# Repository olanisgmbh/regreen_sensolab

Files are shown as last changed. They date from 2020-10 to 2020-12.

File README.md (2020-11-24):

# SensoLAB - make, learn and share

The vision of this project is to implement an universal platform which can be used as a citizen science tool and an interdisciplinary tool for schools.

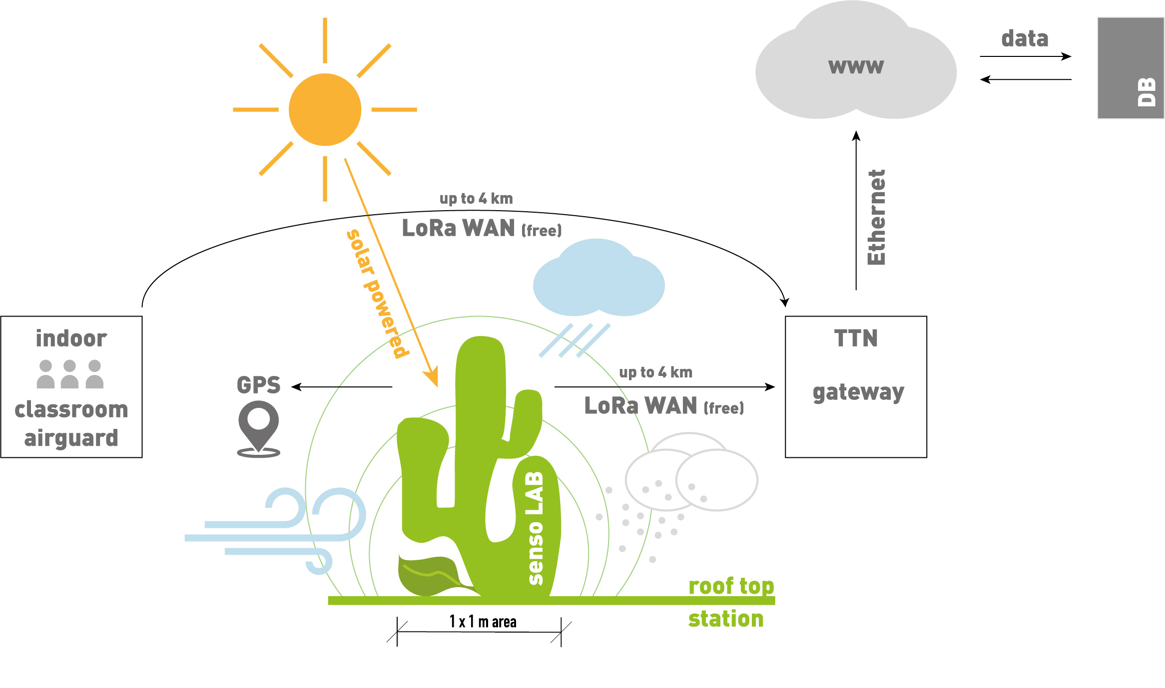
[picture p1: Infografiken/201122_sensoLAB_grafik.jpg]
first prototype


#### the tools You need:

+ screwdrivers
+ solderstation
+ circle cutter
+ punching iron ( 3mm, 8mm )
+ a dremel milling/drilling tool
+ hammer

# Author
Norman Rembarz <norman.rembarz@olanis.de>

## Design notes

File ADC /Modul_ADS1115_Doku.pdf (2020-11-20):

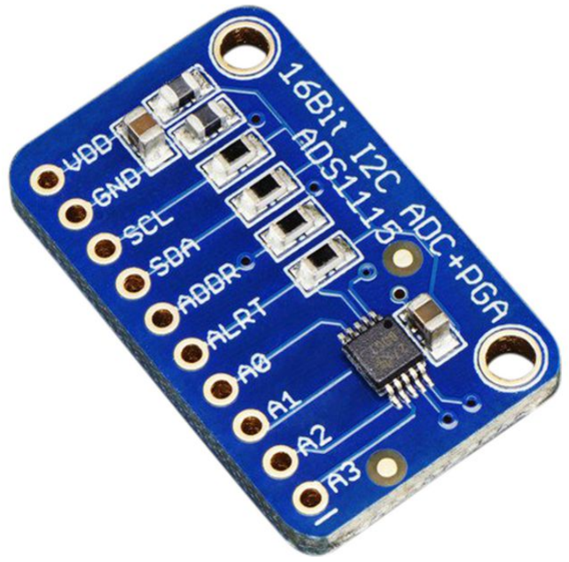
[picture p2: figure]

Von der Spannung zum Bit mit dem ADS1115

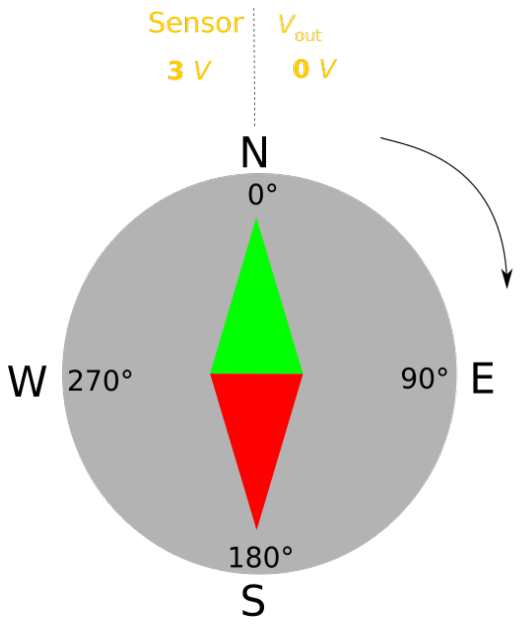
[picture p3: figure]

Was ist ein ADC?
ADC steht für AnalogDigitalConverter, auch A/D-Wandler oder Umsetzer genannt. Dieser ermöglicht es analoge Signale zu digitalen Signalen umzuwandeln. A/D-Umsetzer sind im Bereich der Elektronik unverzichtbar und so gut wie in jedem Elektrogerät vorhanden, so auch in Arduinos. Das Gegenstück hierzu wird DAU genannt. Es gibt viele Arten analoge Signale in digitale umzuwandeln, je nach tiefe handelt es sich dabei um sehr komplexe Prozesse und so sind diese Verfahren bis zum heutigen Tag noch immer Thema aktueller Forschungen im Bereich Elektrotechnik und Informatik.

Auflösung und Sample Rate
Für den Hobbybereich gibt es zwei relevante Werte um mit den Modulen arbeiten zu können, die Auflösung und die Abtastrate. Die Abtastrate bestimmt, wieviele Veränderungen des Signals erfasst werden können. Im Prinzip also der horizontale Abstand der gepunkteten Linien unten im Bild:
Regreen SensorLAB Dokumentation – Wandlung von analog zu digital | Seite 1

Drawing 1: angles and voltage

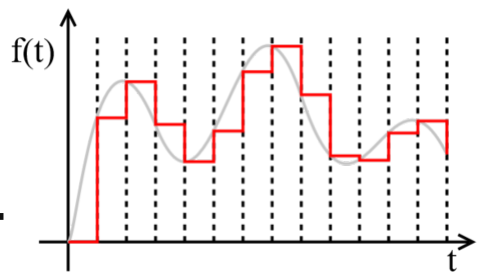
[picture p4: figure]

Die Auflösung kann als Anzahl möglicher Stufen verstanden werden und ist in der nächsten Abbildung als vertikaler Abstand der horizontalen Linien zu verstehen (x).

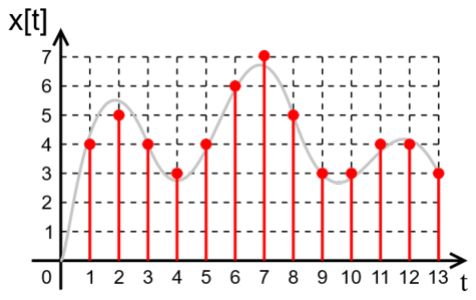
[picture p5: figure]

Was ist ein PGA?
PGA steht für Programmable Gain Amplifier was übersetzt soviel wie "programmierbarer Verstärker" heißt. Diese dienen primär als Operationsverstärker in der Messtechnik, wir verwenden diese Funktion des ADUs auf unseren Modulen nur recht selten, da unsere analogen Sensoren "outof-the-box" für unsere Mikrocontroller lesbare Werte liefern.
Wieso I2C?
Über das I2C-Interface ist eine Kommunikation zwischen dem Modul (auch mehreren Modulen) und Mikrocontrollern mit nur zwei Datenleitungen möglich. Der Umgang mit dem I2C-Bus ist vor allem für Einsteiger empfehlenswert wenn auch nicht mehr Stand der Technik. Alle gängigen Mikrocontroller können über dieses Protokoll kommunizieren und der Umgang der Sensoren auf Modul-Ebene (mit Library) ist besonders leicht zu erlernen. Für fortgeschrittene Benutzer sei an der Stelle die alternativen I2S und CAN genannt.
Regreen SensorLAB Dokumentation – Wandlung von analog zu digital | Seite 2

Installation des Sensors

Damit der Windrichtungsmesser seine Funktion erfüllen kann, muss bei der Installation darauf geachtet werden, dass die NORD-Markierung am Gehäusefuß des Gerätes in die tatsächliche Nord-Richtung zeigt. Hierzu eignet sich die Kompassfunktion im Smartphone oder einer App – wer einen traditionellen mechanischen Kompass zur Hand hat, kann natürlich auch diesen nehmen. Einfach beide N-S-Positionen deckungsgleich aufeinander bringen. Dies ist hinreichend genau für unsere Messungen. Weiterhin ist darauf zu achten, dass die Drehachse des Sensors lotrecht steht.

Funktionsweise

Die Windfahne des Messgeräts ist sehr leichtgängig gelagert und richtet sich zuverlässig nach der vorherrschenden Luftströmung aus. Die Elektronik im Sensor wertet dabei die Stellung der Windfahne aus und wandelt diese in einen Spannungswert zwischen 0 und 3 Volt um (siehe Abbildung 1). Diese Spannung liegt am Signalausgang des Gerätes an. Eine Auslenkung von 90° vom geografischen Nordpol (im UZS) entspricht dabei der Himmelsrichtung OST. Der Spannungswert am Ausgang steigt dabei auf ein Viertel des Wertebereichs an. Am Beispiel OST auf etwa 750 Millivolt.

Um diese Spannung an unserem Mikrocontroller messen zu können, benötigen wir einen Analog zu Digital Konverter, da unser Mikrocontroller keine analogen Eingänge besitzt.
Hier verwenden wir einen ADS1115. Dies ist ein Wandler, der vier analoge Eingänge bereitstellt, welche mit einer 16bit Genauigkeit in digitale Werte umgewandelt werden können und anschließend über die I²C Schnittstelle ausgelesen werden.

Anschluss der Leitungen

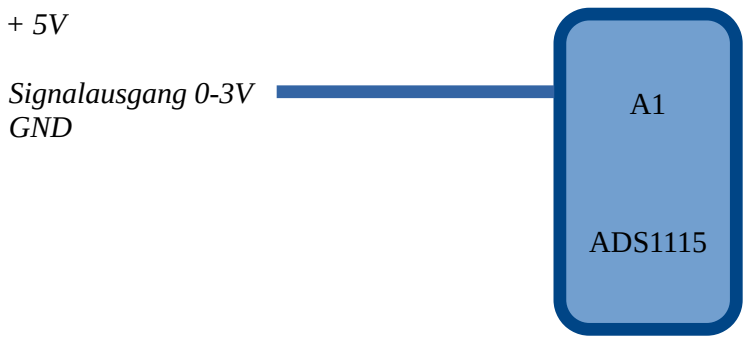
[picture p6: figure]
Signalausgang 0-3V GND; ADS1115

GND

Quellen und Links

- Wikipedia Windrichtungsmessung
- Link zum China-Importeur
Regreen SensorLAB Dokumentation – Wandlung von analog zu digital | Seite 3

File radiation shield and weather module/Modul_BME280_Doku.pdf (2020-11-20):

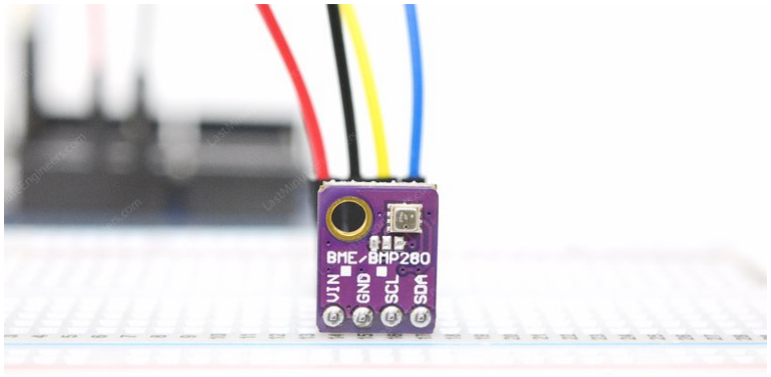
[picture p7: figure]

Temperatur, Luftdruck und Luftfeuchte – der BME280

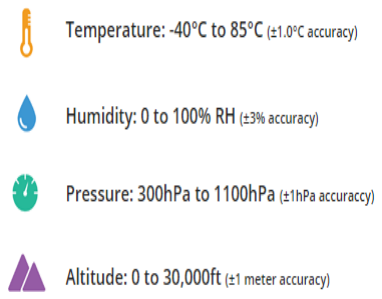
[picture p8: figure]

Bosch Sensortec bringt eine Weltneuheit im Bereich der Sensoren-Technologie auf den Markt: Die integrierte Sensoreinheit BME280 vereint die Sensorfunktionen für Luftdruck, Luftfeuchtigkeit und Temperatur in einem einzigen Gehäuse. Der neue Sensor von Bosch Sensortec wurde speziell entwickelt, um eine Vielzahl neuer und leistungsfähiger Anwendungen zu unterstützen, wie etwa Indoor-Navigation, Smart Home, personalisierte Wetterstationen oder Sport- und Fitness-Applikationen. Die präzise Messfunktion des BME280 ist eine entscheidende Voraussetzung beispielsweise für die Indoor-Navigation mit stockwerksgenauer Höhenermittlung, da diese eine sehr hohe Genauigkeit, einen geringen Temperaturdrift und eine hohe Auflösung erfordert. Der BME280 bestimmt die Luftfeuchtigkeit in nur einer Sekunde – die branchenweit kürzeste Reaktionszeit. Zudem zeichnet er sich durch eine sehr hohe Präzision bei der Messung der Umgebungstemperatur und einen niedrigen Energiebedarf aus.

Auslesen der Daten

Serial.print("Temperature = "); Serial.print(bme.readTemperature()); Serial.println("*C");

Serial.print("Pressure = "); Serial.print(bme.readPressure() / 100.0F); Serial.println("hPa");

Serial.print("Approx. Altitude = "); Serial.print(bme.readAltitude(SEALEVELPRESSURE_HPA));
Serial.println("m");
Regreen SensorLAB Dokumentation – Wandlung von analog zu digital | Seite 1

Drawing 1: Wertebereich des BME280

Serial.print("Humidity = "); Serial.print(bme.readHumidity()); Serial.println("%");

I²C Adresse
0x76 (ist die Standardadresse)
0x77 (selektiv über spezielle Beschaltung)

Anschluss der Leitungen

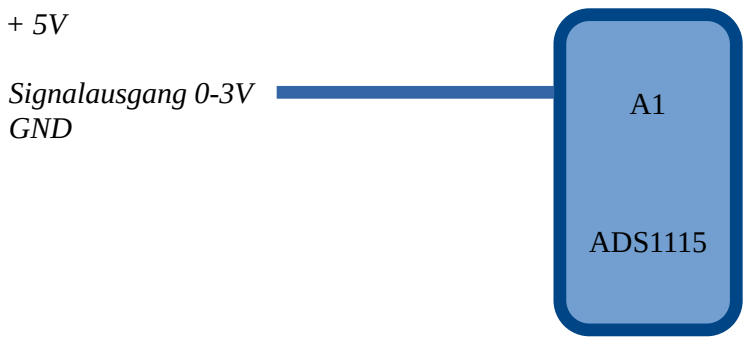
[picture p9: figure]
Signalausgang 0-3V GND; ADS1115

GND

Quellen und Links

- Wikipedia Windrichtungsmessung
- Link zum China-Importeur
Regreen SensorLAB Dokumentation – Wandlung von analog zu digital | Seite 2

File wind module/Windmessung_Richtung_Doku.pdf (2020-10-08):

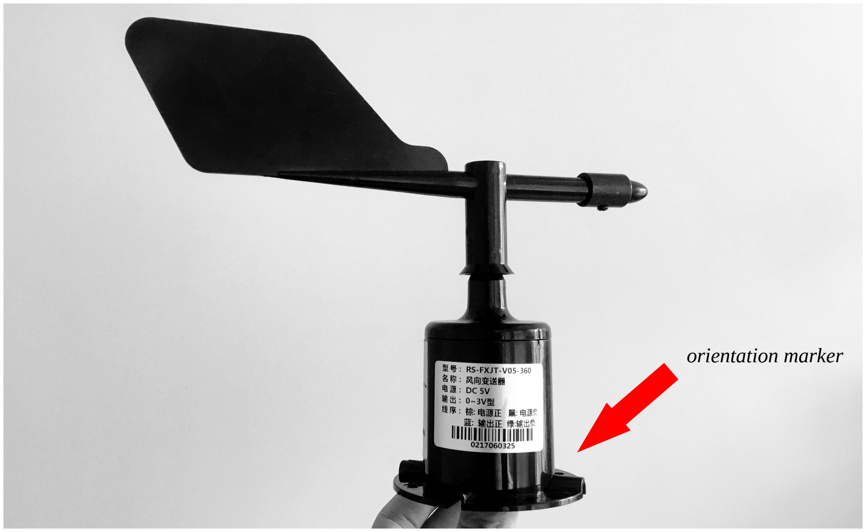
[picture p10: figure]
orientation marker

Windrichtungsmesser mit analogem Signal-Ausgang am ADS1115 (analog zu digital Konverter)


Installation des Sensors

Damit der Windrichtungsmesser seine Funktion erfüllen kann, muss bei der Installation darauf geachtet werden, dass die NORD-Markierung am Gehäusefuß des Gerätes in die tatsächliche Nord-Richtung zeigt. Hierzu eignet sich die Kompassfunktion im Smartphone oder einer App – wer einen traditionellen mechanischen Kompass zur Hand hat, kann natürlich auch diesen
nehmen. | Einfach | beide | N-S-Positionen | deckungsgleich
aufeinander bringen. Dies ist hinreichend genau für unsere Messungen. Weiterhin ist darauf zu achten, dass die Drehachse des Sensors lotrecht steht.

Funktionsweise

Die Windfahne des Messgeräts ist sehr leichtgängig gelagert und richtet sich zuverlässig nach der vorherrschenden Luftströmung aus. Die Elektronik im Sensor wertet dabei die Stellung der Windfahne aus und wandelt diese in einen Spannungswert zwischen 0 und 3 Volt um (siehe Abbildung 1). Diese Spannung liegt am Signalausgang des Gerätes an. Eine Auslenkung von 90° vom geografischen Nordpol (im UZS) entspricht dabei der Himmelsrichtung OST. Der Spannungswert am Ausgang steigt dabei auf ein Viertel des Wertebereichs an. Am Beispiel OST auf etwa 750 Millivolt.

Regreen SensorLAB Dokumentation – Messung der Windrichtung | Seite 1

Drawing 1: angles and voltage

Um diese Spannung an unserem Mikrocontroller messen zu können, benötigen wir einen Analog zu Digital Konverter, da unser Mikrocontroller keine analogen Eingänge besitzt.
Hier verwenden wir einen ADS1115. Dies ist ein Wandler, der vier analoge Eingänge bereitstellt, welche mit einer 16bit Genauigkeit in digitale Werte umgewandelt werden können und anschließend über die I²C Schnittstelle ausgelesen werden.

Anschluss der Leitungen

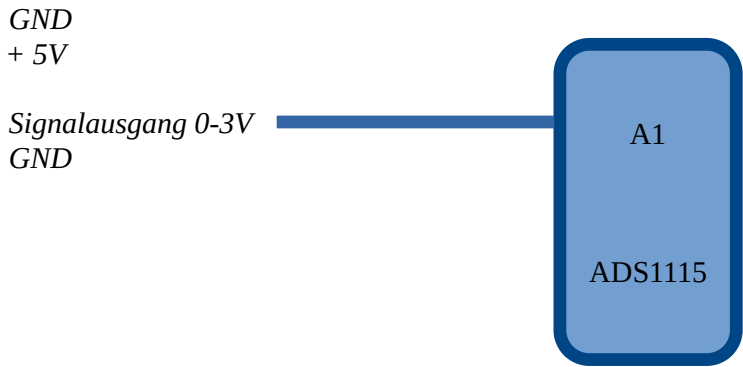
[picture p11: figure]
GND + 5V; Signalausgang 0-3V GND; ADS1115

Regreen SensorLAB Dokumentation – Messung der Windrichtung | Seite 2

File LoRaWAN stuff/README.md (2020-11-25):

# How to install your LoRa Gateway

### Why this technology?

# Where is the best place?

# Author
Norman Rembarz <norman.rembarz@olanis.de>
Philpp Zimmer <philipp.zimmer@olanis.de>

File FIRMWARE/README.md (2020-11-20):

# How to flash the firmware on T-beam

The vision of this project is to implement an universal platform which can be used as a citizen science tool and an interdisciplinary tool for schools.

# All your base belong to us

# Author
Norman Rembarz <norman.rembarz@olanis.de>
Philpp Zimmer <philipp.zimmer@olanis.de>

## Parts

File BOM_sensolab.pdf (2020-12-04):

## complete bill of material - sensoLAB

no. | image | amount | name | specification | avg.price (€) | source | link
1 | | 1 | Flachdachständer / pole stand | 1x1m , 1m length of pole | 40,00 EUR | ebay | click (https://www.ebay.de/itm/Flachdachstander-1m-Mast-4x50x50cm-SAT-Antenne-Standfus-Terrasse-Balkon-Stander/160658726749)
2 | | 4 | Betonplatte / concrete plate | 50x50cm, 4cm thickness | 3,00 EUR | local hardware store | click (https://www.bauhaus.info/terrassenplatten-gehwegplatten/ehl-waschbetonplatte/p/22264864)
3 | | 8 | DN110 angle 45° | DN110 HT | 2,00 EUR | local hardware store | click (https://www.hornbach.de/shop/HT-Bogen-DN-110-45-Grad/266988/artikel.html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)
4 | | 1 | DN110 Muffe | DN110 HT | 2,00 EUR | local hardware store | click (https://www.hornbach.de/shop/HT-Muffe-DN-110-grau/267163/artikel.html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)

5 | 5 | DN110 Deckel / cap | DN110 HT | 1,00 EUR | local hardware store | click (https://www.hornbach.de/shop/HT-Muffenstopfen-DN-110/267185/artikel.html)
6 | 3 | DN110 Rohr / tube | DN110 HT 500mm | 2,00 EUR | local hardware store | click (https://www.obi.de/ht-abflussrohre/marley-ht-rohr-mit-steckmuffe-dn-110-grau-500-mm/p/7436843)
7 | 3 | DN110 Rohr / tube | DN110 HT 250mm | 2,00 EUR | local hardware store | click (https://www.obi.de/ht-abflussrohre/marley-ht-rohr-mit-steckmuffe-dn-110-grau-250-mm/p/7436793)
8 | 1 | DN110 Reinigungsrohr / cleaning tube | DN110 HT | 8,00 EUR | local hardware store | click (https://www.obi.de/ht-reinigungsrohre/marley-ht-reinigungsrohr-dn-110/p/7434772)

9 | 6 | threaded rod | M8 1000mm, stainless steel | 5,00 EUR | local hardware store | click (https://www.edelstahl-niro.de/gewindestange-1000mm-p-1623.html)
10 | 8 | Rohrschelle klein | | 1,50 EUR | local hardware store
11 | 8 | Rohrschelle groß | | 2,00 EUR | local hardware store
100 | 1 | solar panel | 12V, 50W with cables
50,00 EUR | ebay/amazon

110 | 1 | solar panel regulator | 12V MPPT | 20,00 EUR | ebay/amazon | click (https://www.ebay.de/itm/30A-Solar-Laderegler-Controller-MPPT-Solar-Panel-USB-Regulator-12V-24V-DHL/233790688162)
120 | 1 | 12V battery | 12V / 12Ah | 30,00 EUR | ebay/amazon | click (https://www.ebay.de/itm/Kung-Long-VdS-WP12-12-12V-12Ah-AGM-Blei-Accu-Batterie-wartungsfrei-VdS-battery/202978835868)
130 | 1 | cable red | 6qmm, red, 1m | 4,00 EUR | ebay/amazon
140 | 1 | cable black | 6qmm, black 1m | 4,00 EUR | ebay/amazon

150 | 1 | solar cable connector | female | 2,00 EUR | ebay/amazon | click (https://www.ebay.de/itm/Solarstecker-Solar-Stecker-Buchse-Kupplung-Kabel-2-5-6-mm-DE-STOCK/402563089656)
160 | 1 | solar cable connector | male | 2,00 EUR | ebay/amazon | click (https://www.ebay.de/itm/Solarstecker-Solar-Stecker-Buchse-Kupplung-Kabel-2-5-6-mm-DE-STOCK/402563089656)
170 | 1 | pole mounting box | | 25,00 EUR | WLAN-shop24 | click (https://www.wlan-shop24.de/kunststoff-gehaeuse-mastmontage-wetterfest)

200 | 10 | plastic flowerpot coaster | perimeter=130mm, heigth=10mm, white | 15,00 EUR | ebay/amazon | click (https://www.ebay.de/itm/Untersetzer-fur-Blumenkubel-Blumentopf-Blumenuntersetzer-Rund-9-Grosen-4-Farben/141374601466)
210 | 1 | threaded rod | M3x1000mm , stainless steel | 4,00 EUR | local hardware store | click (https://www.ebay.de/itm/Gewindestangen-M3-bis-M20-DIN-975-976-A2-Edelstahl-1-bis-5-Stuck/172937101238)
220 | 6 | M3 nut | stainless steel | 1,00 EUR | local hardware store
230 | 35 | washer 3,2x10 | Stainless steel | 1,00 EUR | Local hardware
240 | 1 | acrylic tube | 3mm/5mm, 1000mm, transparent | 4,00 EUR | ebay/amazon | click (https://www.ebay.de/itm/3-75-m-Acrylrohr-XT-ausen-5-mm-innen-3-mm-transparent-Lange-1-m/322116941955)

250 | 5 | Kabelverschraubung | PG7 10mm | 5,00 EUR | reichelt.de | click (https://www.reichelt.de/kabelverschraubung-pg7-grau-ral-7035-10er-pack-rnd-465-00384-p221969.html?PROVID=2788)
260 | 2 | rubber mat for sealings | 200x300mm, 1mm thick, black | 4,00 EUR | ebay/amazon | click (https://www.ebay.de/itm/Antivibrations-Gummimatte-Gummiplatte-SBR-von-1-bis-4mm-Grose-von-100-bis-500mm/323850603389)
270 | 1 | acrylic dome | 100mm | 14,00 EUR | ebay (www.acrylhaus .com) | click (https://www.ebay.de/itm/Halbkugel-Halbschale-aus-Acrylglas-Plexiglas-100mm/162235277237)
280 | 1 | acrylic ronde | 130mm/4mm | 5,00 EUR | ebay | click (https://www.ebay.de/itm/PLEXIGLAS-RUND-50-1000-mm-4-mm-DICK-ACRYLGLAS-MARKE-DECKEL-GLASKLAR-RONDE/264446582865)
290 | 1 | housing ventilation plug | M12 | 5,00 EUR | www.tme.eu | click (https://www.tme.eu/de/details/gvppa-m12l/gehause-sonstiges-zubehor/fibox/gvppa-m12l/?brutto=1)

300 | 1 | BME280 breakout | PCB with mounting holes, GY-BME280 (3.3V) | 5 | ebay/amazon | click (https://www.tme.eu/de/details/gvppa-m12l/gehause-sonstiges-zubehor/fibox/gvppa-m12l/?brutto=1)
310 | 1 | SPS30 sensor | Sensirion | 38,00 EUR | sos-electronic / olanis | click (https://www.soselectronic.de/products/sensirion/sps30-2-304234)
320 | 1 | SCD30 | Sensirion | 45,00 EUR | sos-electronic / olanis | click (https://www.soselectronic.de/products/sensirion/scd30-5-290529)
330 | 1 | VEML7700 | | 10,00 EUR | olanis

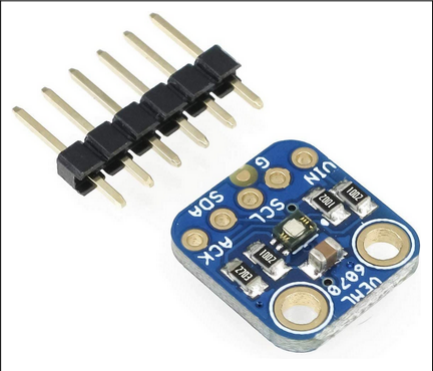
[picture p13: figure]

340 | 1 | VEML6070 | | 10,00 EUR | olanis
350 | 1 | ADS1115 | | 7,00 EUR | olanis
360 | 1 | anemometer | Output 0-3V | 70,00 EUR | ebay/alibaba

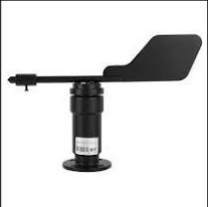
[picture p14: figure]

370 | 1 | wind direction | Output 0-3V | 60,00 EUR | ebay/alibaba
380 | 1 | rain gauge | | 30,00 EUR | ebay/alibaba
390 | 1 | Niederschlagsensor | | 10,00 EUR | ebay
400 | 1 | I²S microphone | | 10,00 EUR | ebay

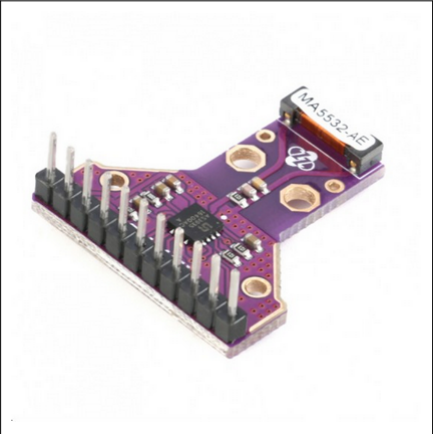
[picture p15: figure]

410 | 1 | AS3935 | I²C connection | 20,00 EUR | ebay

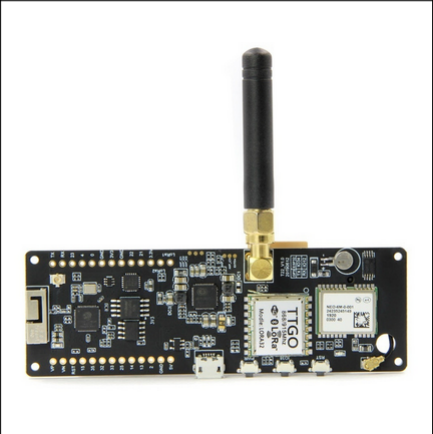
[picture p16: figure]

420 | 1 | TTGO T-Beam | V1.1, 868MHz (EU) | 30,00 EUR | ebay

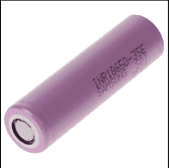
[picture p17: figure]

430 | 1 | Battery 18650 | 3.7V | 6,00 EUR | ebay
440 | 1 | antenna pigtail | SMA | 3,00 EUR | ebay

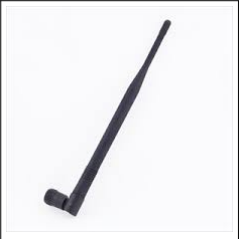
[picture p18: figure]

450 | 1 | antenna | For 868MhZ, SMA connector | 9,00 EUR | ebay

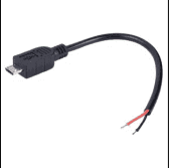
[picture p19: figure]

460 | 1 | MicroUSB cable | Power cable, 15cm DeLock | 3,00 EUR | ebay
total | 624,50 EUR
500 | 1 | LoRaWAN Gateway | Kit with antenna, gateway and power supply
280,00 EUR | ebay

total with
gateway

904,50 EUR

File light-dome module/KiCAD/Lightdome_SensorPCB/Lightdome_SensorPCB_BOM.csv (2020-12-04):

Reference | Value | Footprint | Datasheet | MANUFACTURER | PARTREV | STANDARD
U1 | VEML6070 | VEML6070:PHODET_VEML6070 |  | Vishay
U2 | VEML7700-TT | VEML7700-TT:XDCR_VEML7700-TT |  | Vishay | 1.3 | Manufacturer Recommendation
U3 | P82B715D | SOIC127P599X175-8N
R1 | 330 | Resistor_SMD:R_1206_3216Metric_Pad1.42x1.75mm_HandSolder | ~
J1 | Conn_01x04 | Connector_JST:JST_PH_B4B-PH-SM4-TB_1x04-1MP_P2.00mm_Vertical | ~
R2 | 330 | Resistor_SMD:R_1206_3216Metric_Pad1.42x1.75mm_HandSolder | ~
R3 | 270K | Resistor_SMD:R_0603_1608Metric_Pad1.05x0.95mm_HandSolder | ~
C1 | 100n | Capacitor_SMD:C_0603_1608Metric_Pad1.05x0.95mm_HandSolder | ~

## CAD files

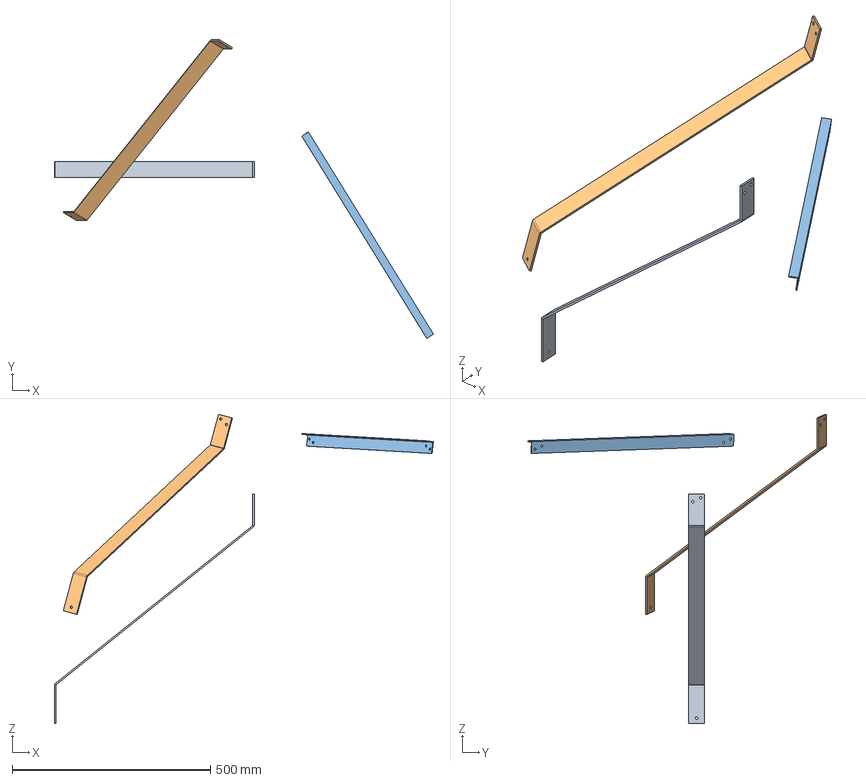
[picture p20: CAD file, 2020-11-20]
solar panel mount/drawings/solar_panel_mount_assembly.FCStd
956.1 x 753.7 x 780.5 mm
solar_panel_mount_bracket_1_003
solar_panel_mount_bracket_1_001
solar_panel_mount_bracket_2_002

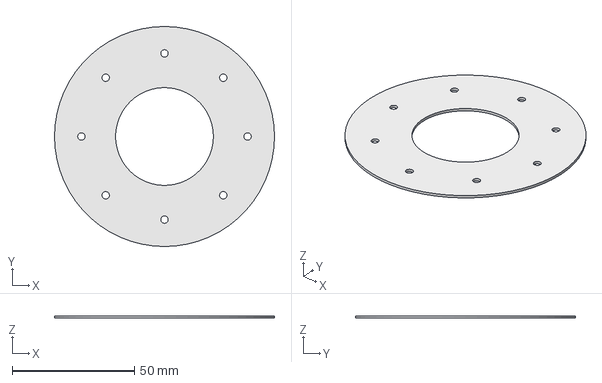
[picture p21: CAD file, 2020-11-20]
light-dome module/drawings/step/rubber_ring_spacer.step
90.0 x 90.0 x 1.00 mm

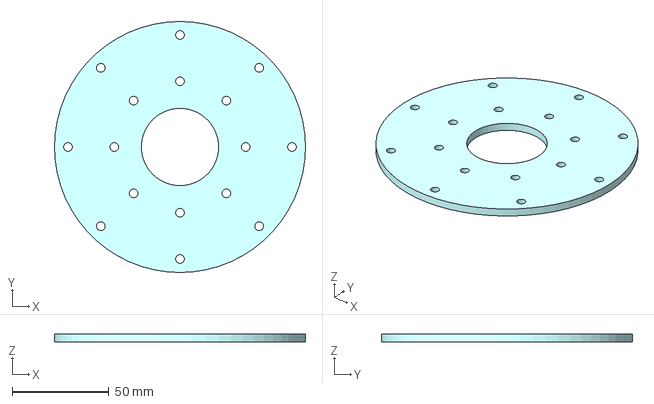
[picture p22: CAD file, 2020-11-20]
light-dome module/drawings/top_plate_LightDome.FCStd
130.0 x 130.0 x 4.00 mm

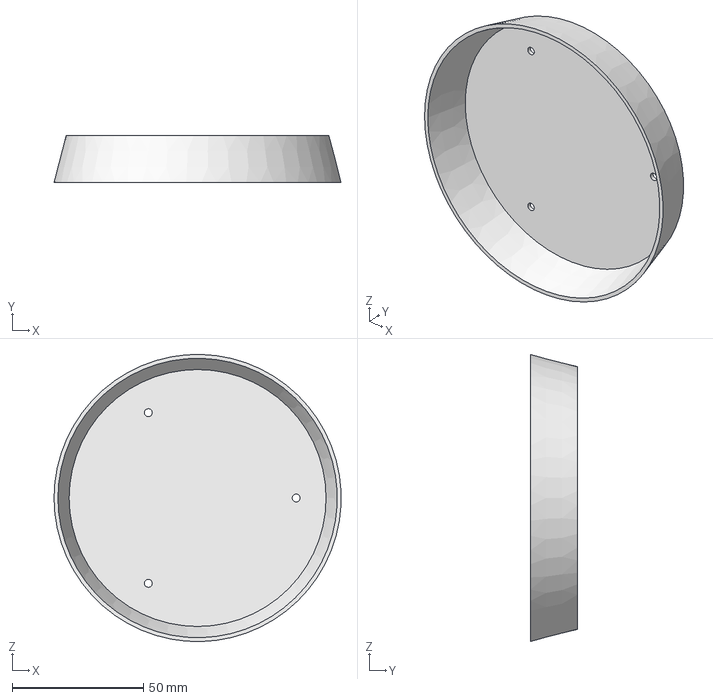
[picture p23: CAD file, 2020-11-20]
radiation shield and weather module/radiation shield/radiation_shield_dish_top.FCStd
109.2 x 18.0 x 109.3 mm

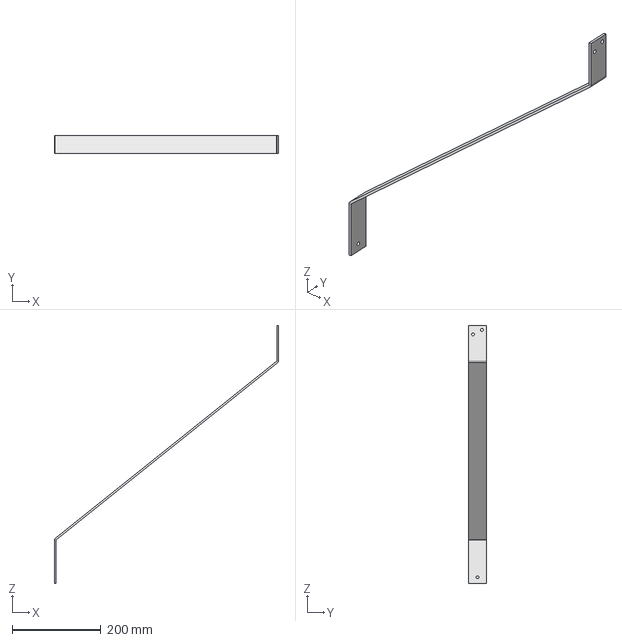
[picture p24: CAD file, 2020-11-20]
solar panel mount/drawings/solar_panel_mount_bracket_1_drawing.FCStd
504.0 x 40.0 x 580.0 mm

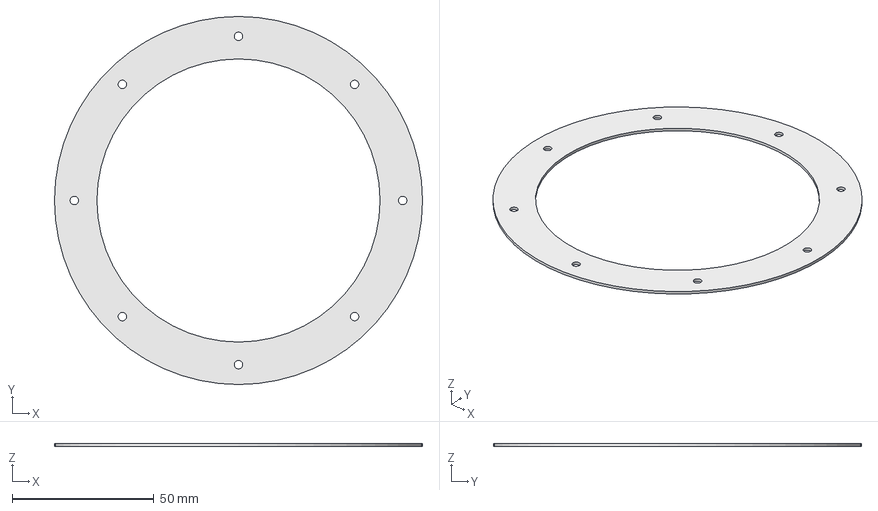
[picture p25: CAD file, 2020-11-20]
light-dome module/drawings/Rubber_Ring_II_LightDome.FCStd
130.0 x 130.0 x 1.00 mm

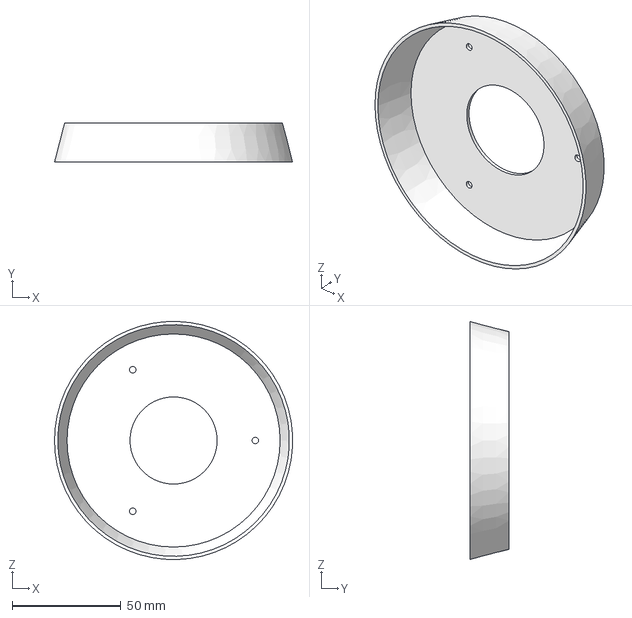
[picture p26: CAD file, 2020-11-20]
radiation shield and weather module/radiation shield/radiation_shield_dish.FCStd
109.2 x 18.0 x 109.3 mm

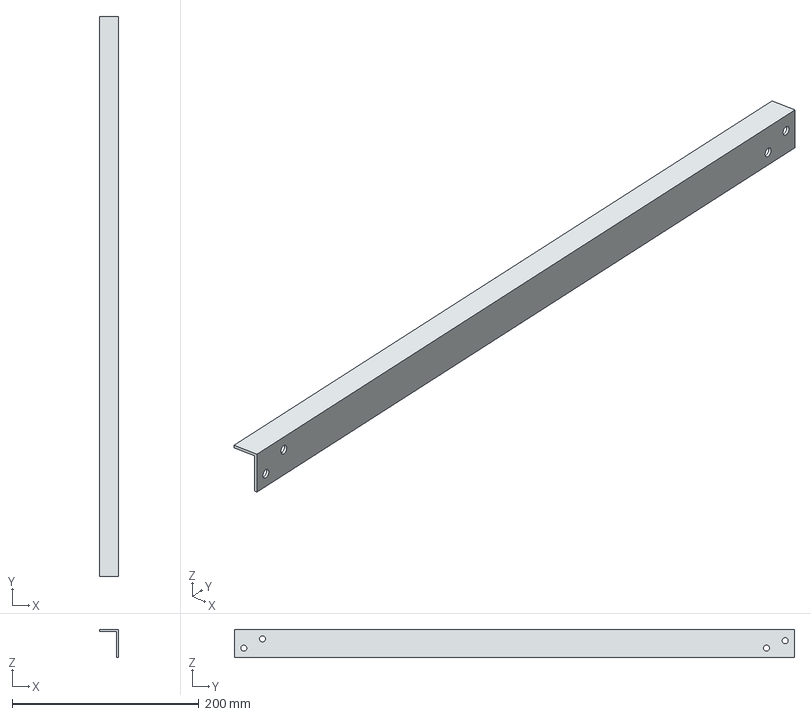
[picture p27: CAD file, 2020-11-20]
solar panel mount/drawings/solar_panel_mount_bracket_2.FCStd
20.0 x 600.0 x 30.0 mm

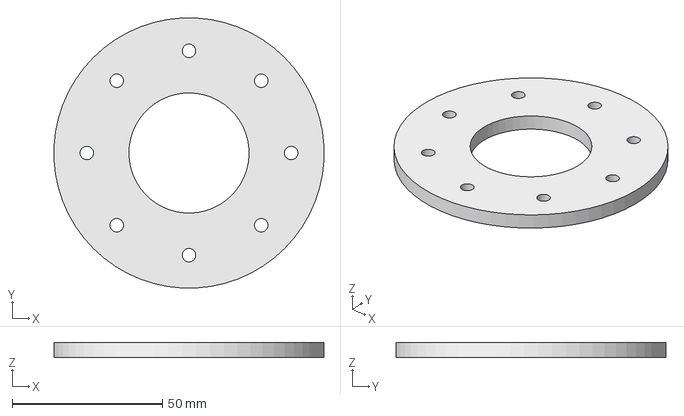
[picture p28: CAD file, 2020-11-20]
light-dome module/drawings/step/acrylic_spacer.step
89.9 x 89.9 x 5.00 mm

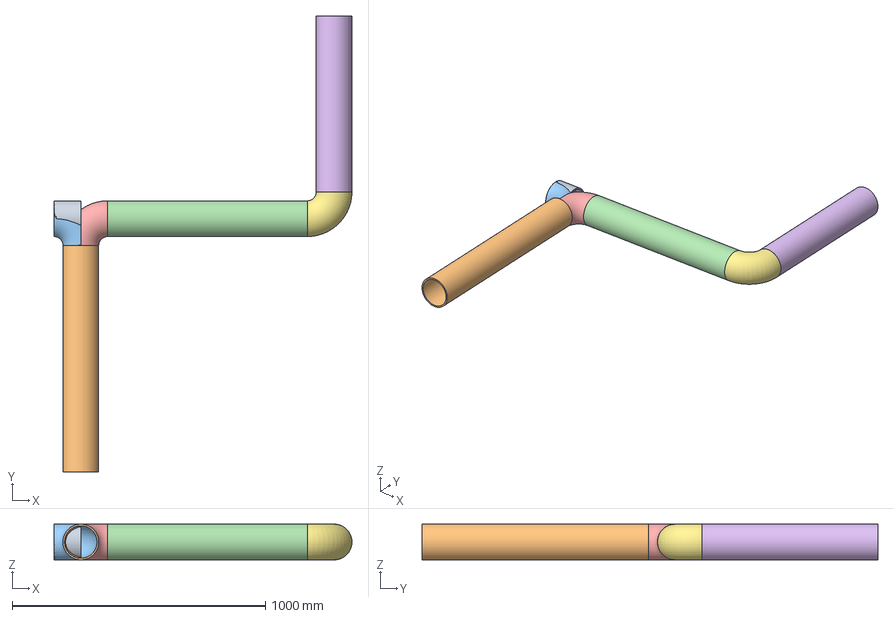
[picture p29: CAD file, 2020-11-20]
light-dome module/drawings/Sensolab_Tube_korpus.FCStd
1176.6 x 1800.0 x 141.3 mm
Tubo
Tubo001
Curva
Tubo002
Curva001
Tubo003
Curva002

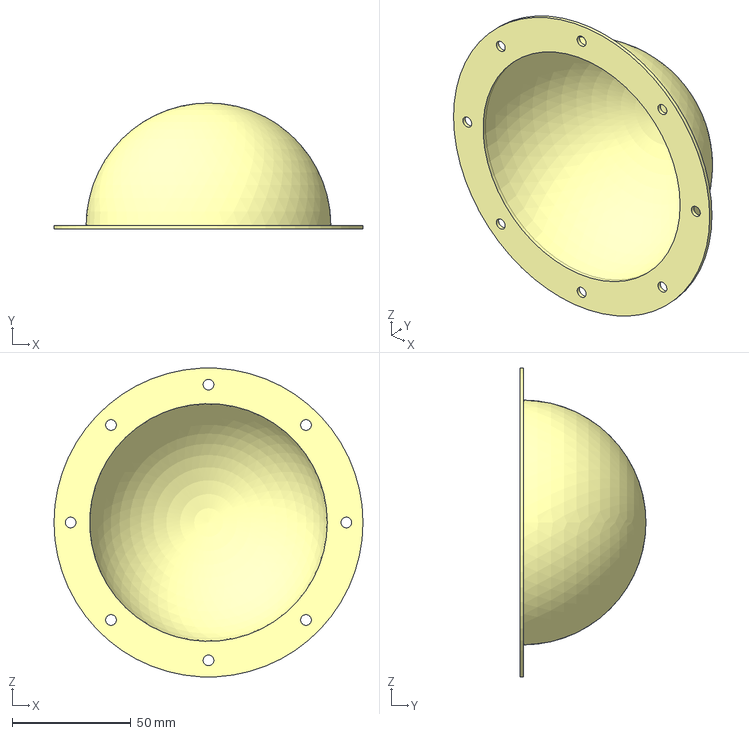
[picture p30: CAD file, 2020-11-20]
light-dome module/drawings/step/acrylic_kuppel.step
130.0 x 53.0 x 129.8 mm

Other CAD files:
light-dome module/drawings/step/Assembly_Kuppel.FCStd
light-dome module/drawings/step/mount_plate_kuppel.step
light-dome module/drawings/Rubber_Ring_I_LightDome.FCStd
light-dome module/drawings/Acryl_Ring_spacer_LightDome.FCStd
light-dome module/drawings/step/rubber_ring_kuppel.step
solar panel mount/drawings/solar_panel_mount_bracket_1.FCStd
light-dome module/drawings/kuppel_LightDome.FCStd

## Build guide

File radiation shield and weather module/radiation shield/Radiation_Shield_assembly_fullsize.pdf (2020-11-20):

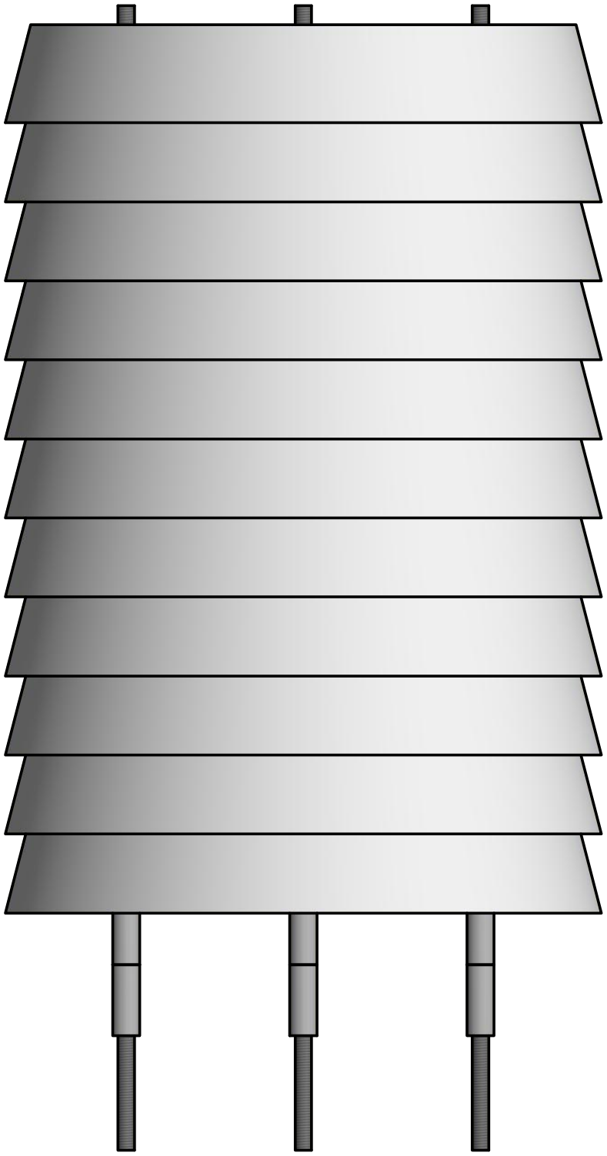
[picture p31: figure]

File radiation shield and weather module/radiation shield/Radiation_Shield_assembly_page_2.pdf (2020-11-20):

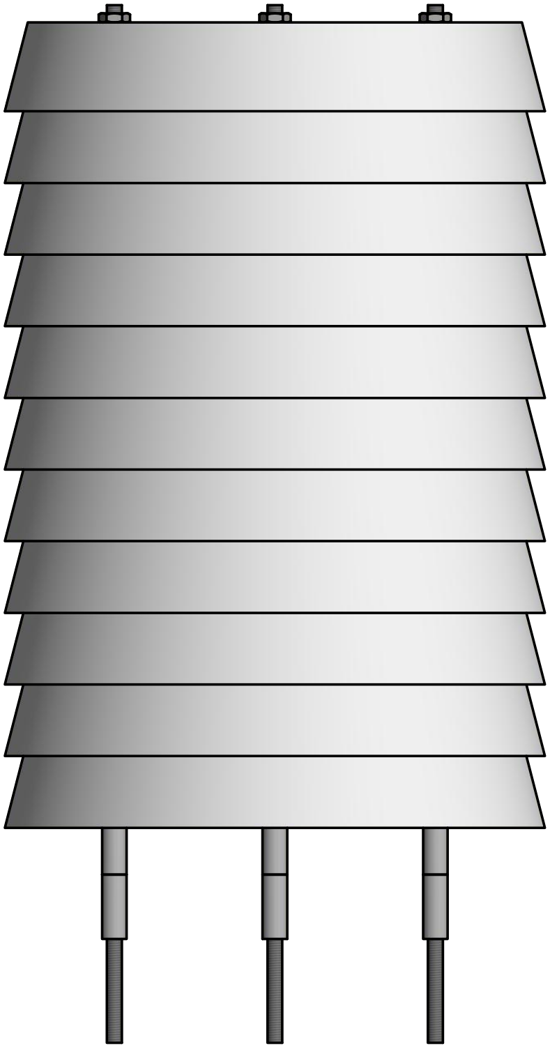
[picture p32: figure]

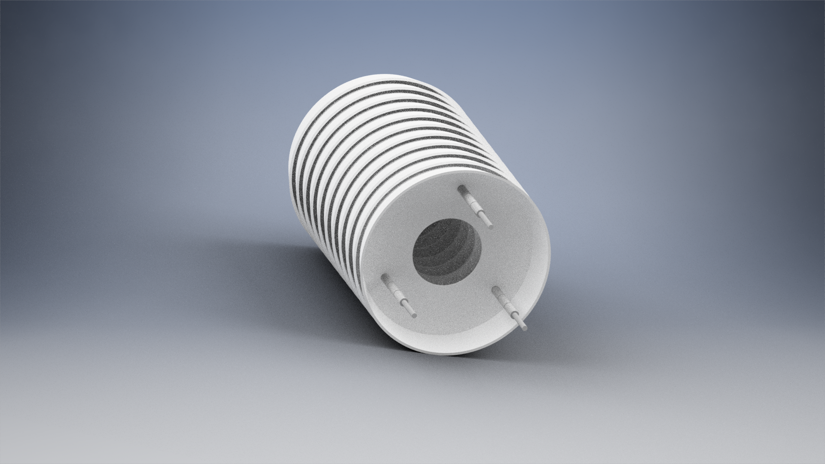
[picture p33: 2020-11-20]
radiation shield and weather module/radiation shield/Radiation_Shield_assembly_6.png

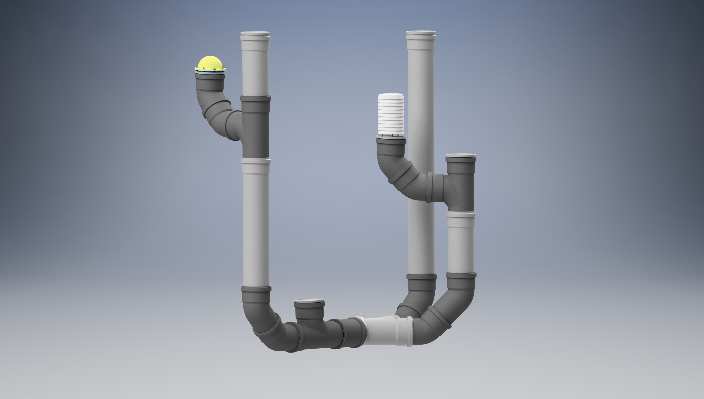
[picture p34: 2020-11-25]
Regreen_Sensolab_TubeCase/Tubes_assembly.png

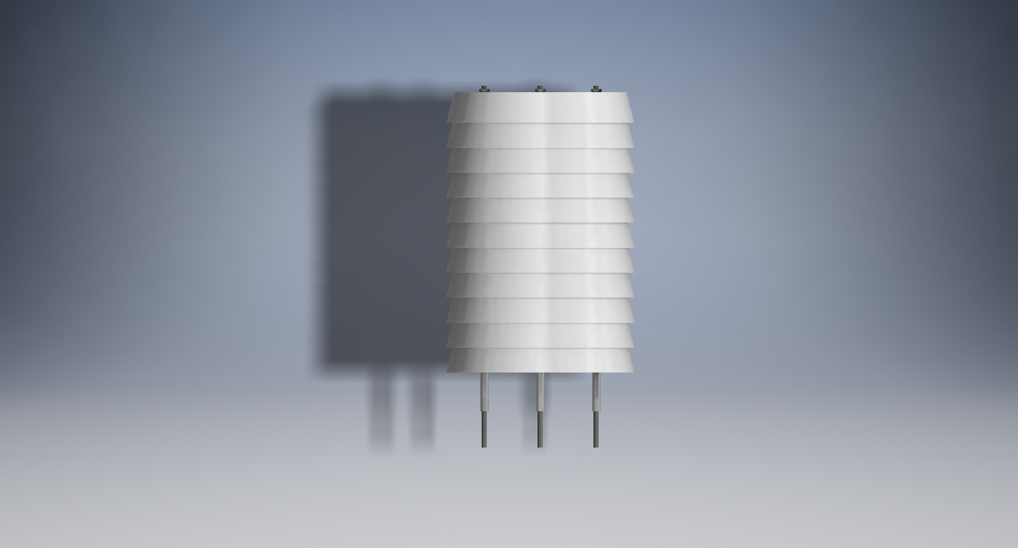
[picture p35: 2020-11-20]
radiation shield and weather module/radiation shield/Radiation_Shield_assembly_2.png

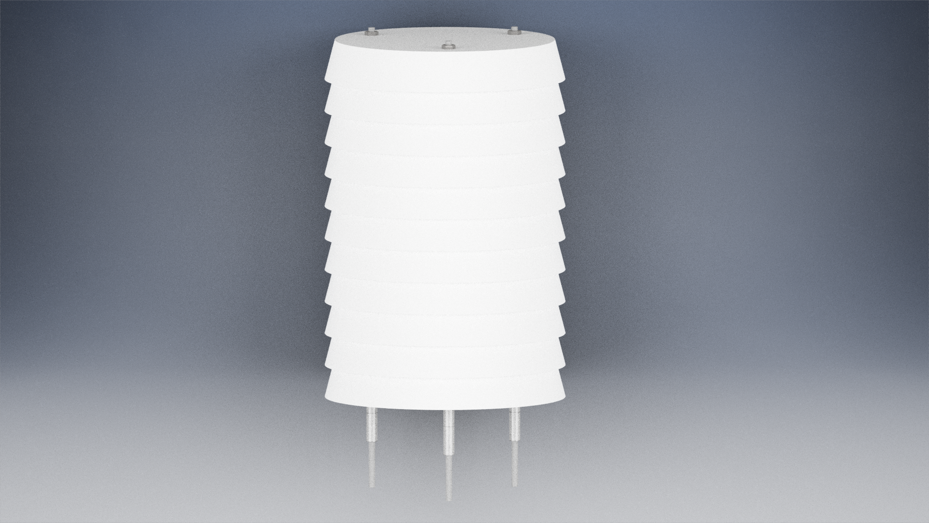
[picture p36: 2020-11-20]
radiation shield and weather module/radiation shield/Radiation_Shield_assembly_5.png

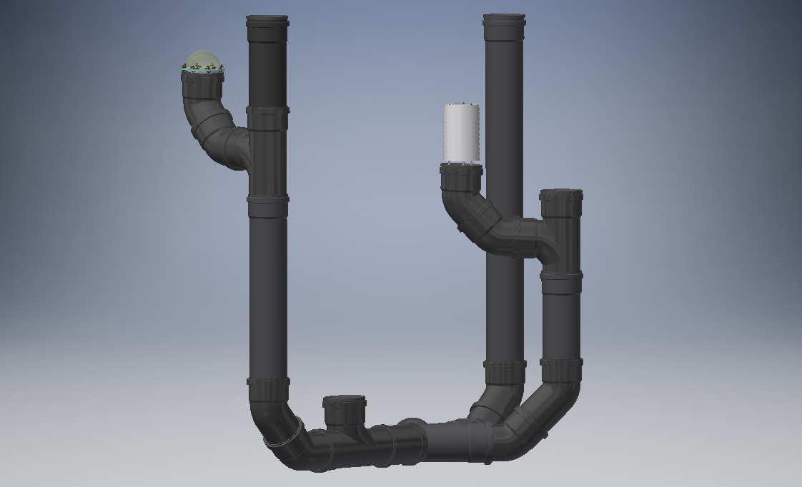
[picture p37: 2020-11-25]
Regreen_Sensolab_TubeCase/Tubes_assembly_2.png

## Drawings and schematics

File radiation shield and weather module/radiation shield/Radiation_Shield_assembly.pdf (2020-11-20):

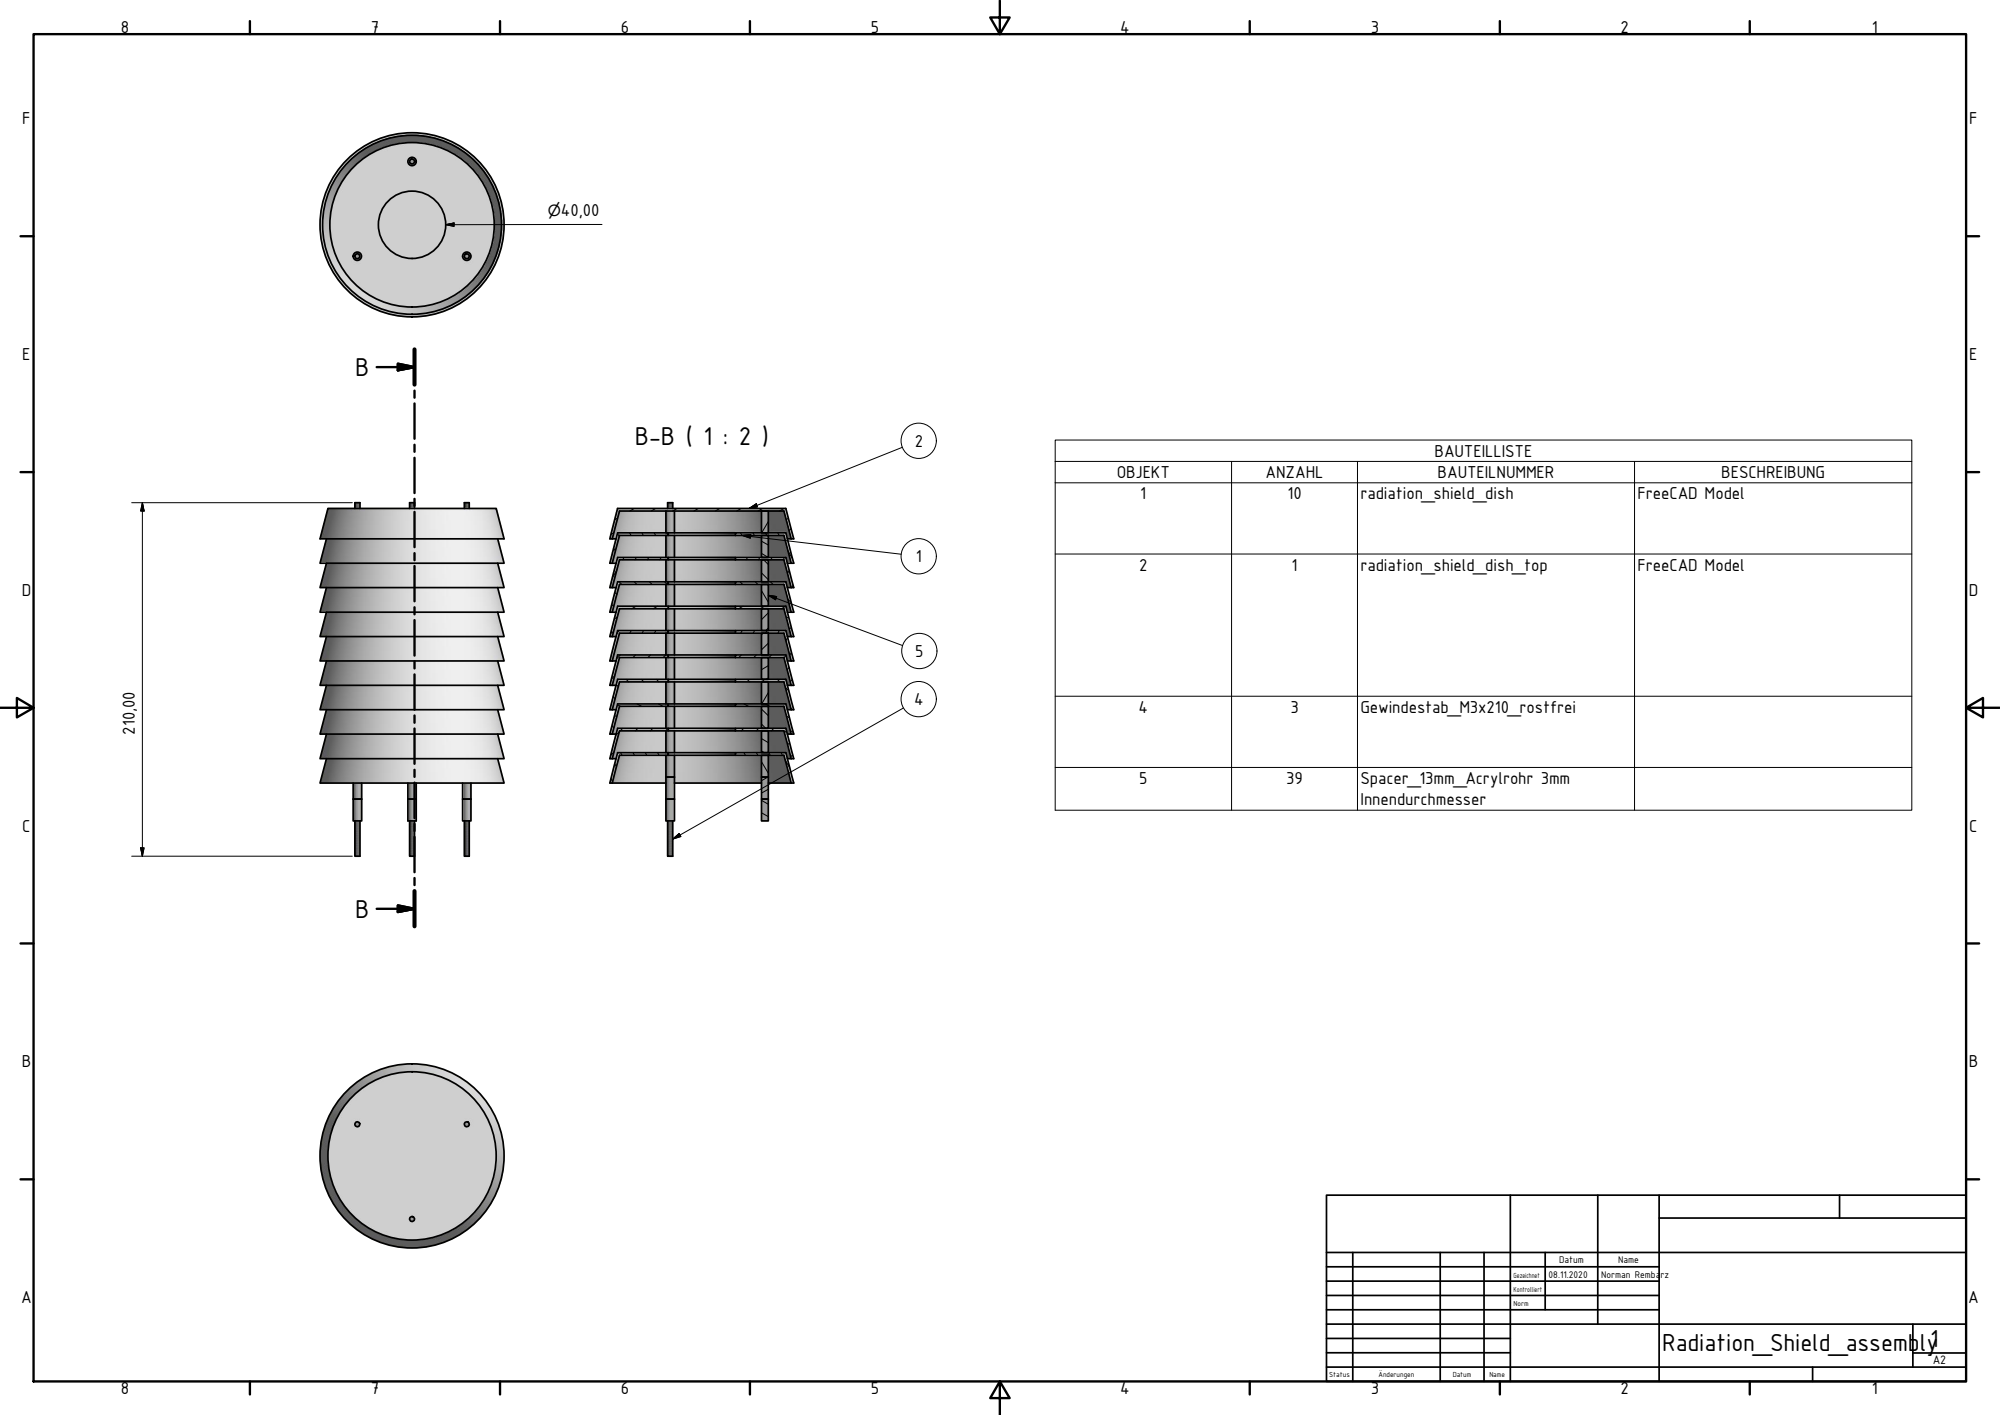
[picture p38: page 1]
BAUTEILLISTE; OBJEKT; ANZAHL; BAUTEILNUMMER; BESCHREIBUNG; radiation_shield_dish; FreeCAD Model; radiation_shield_dish_top; Gewindestab_M3x210_rostfrei; Spacer_13mm_Acrylrohr 3mm Innendurchmesser; Radiation_Shield_assembly; Status; |nderungen; Datum; Name; Gezeichnet; Kontrolliert; Norm; Norman Rembarz

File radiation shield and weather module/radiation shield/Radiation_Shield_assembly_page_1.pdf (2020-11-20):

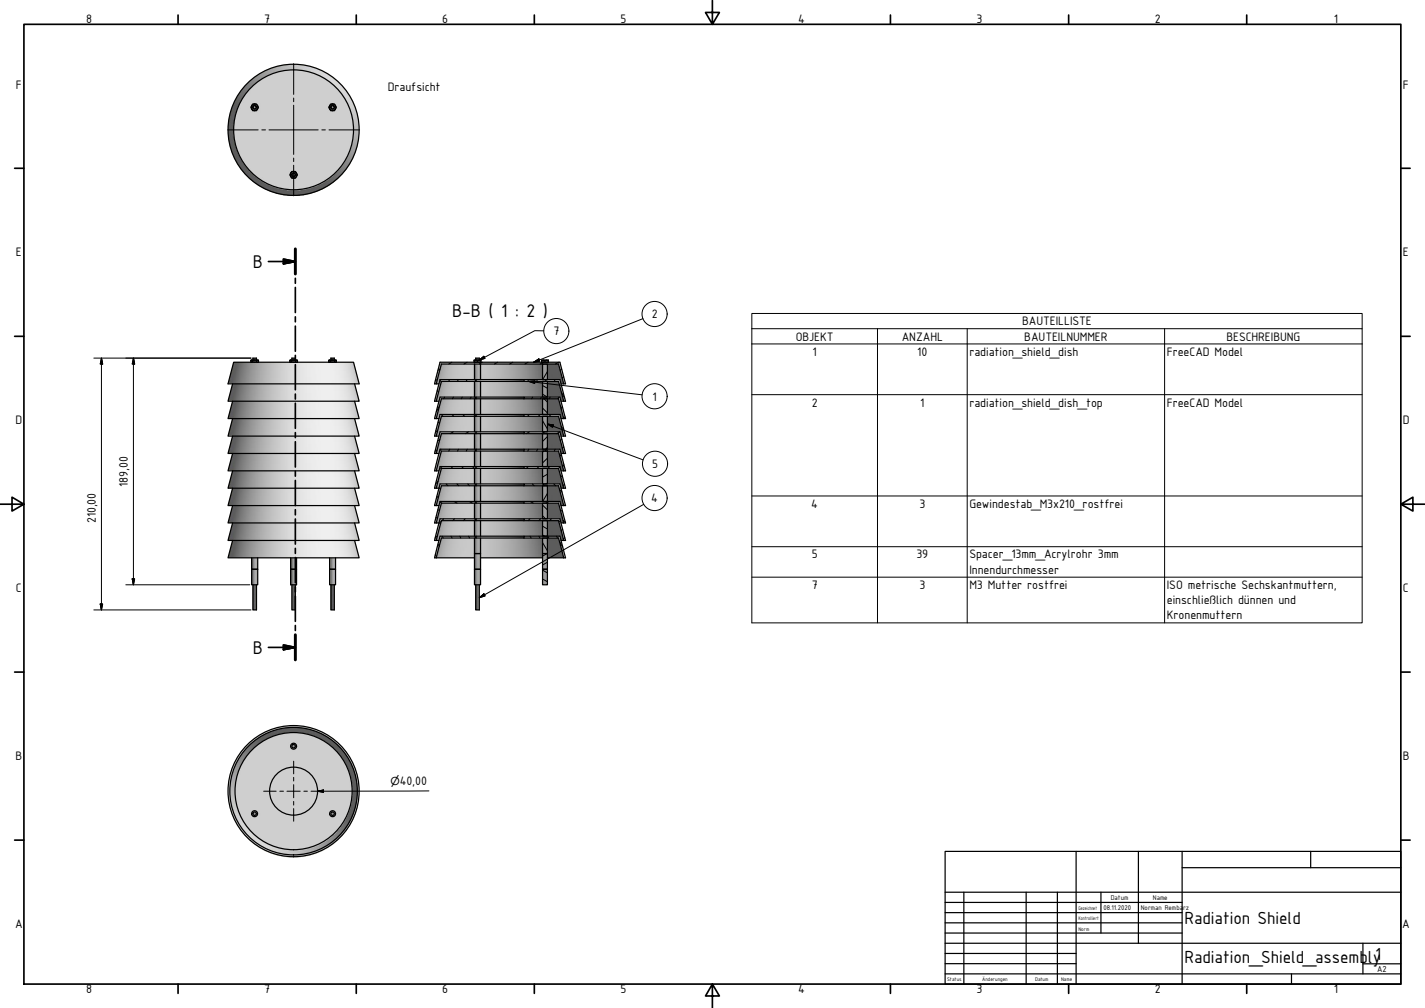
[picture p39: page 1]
BAUTEILLISTE; OBJEKT; ANZAHL; BAUTEILNUMMER; BESCHREIBUNG; radiation_shield_dish; FreeCAD Model; radiation_shield_dish_top; M3 Mutter rostfrei; Radiation Shield; Radiation_Shield_assembly; Status; |nderungen; Datum; Name; Gezeichnet; Kontrolliert; Norm; Norman Rembarz; Draufsicht

4 | 3 | Gewindestab_M3x210_rostfrei

5 | 39 | Spacer_13mm_Acrylrohr 3mm Innendurchmesser

ISO metrische Sechskantmuttern,
einschlielich d¯nnen und
Kronenmuttern

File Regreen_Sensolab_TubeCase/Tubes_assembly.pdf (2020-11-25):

# y_AI 11 22

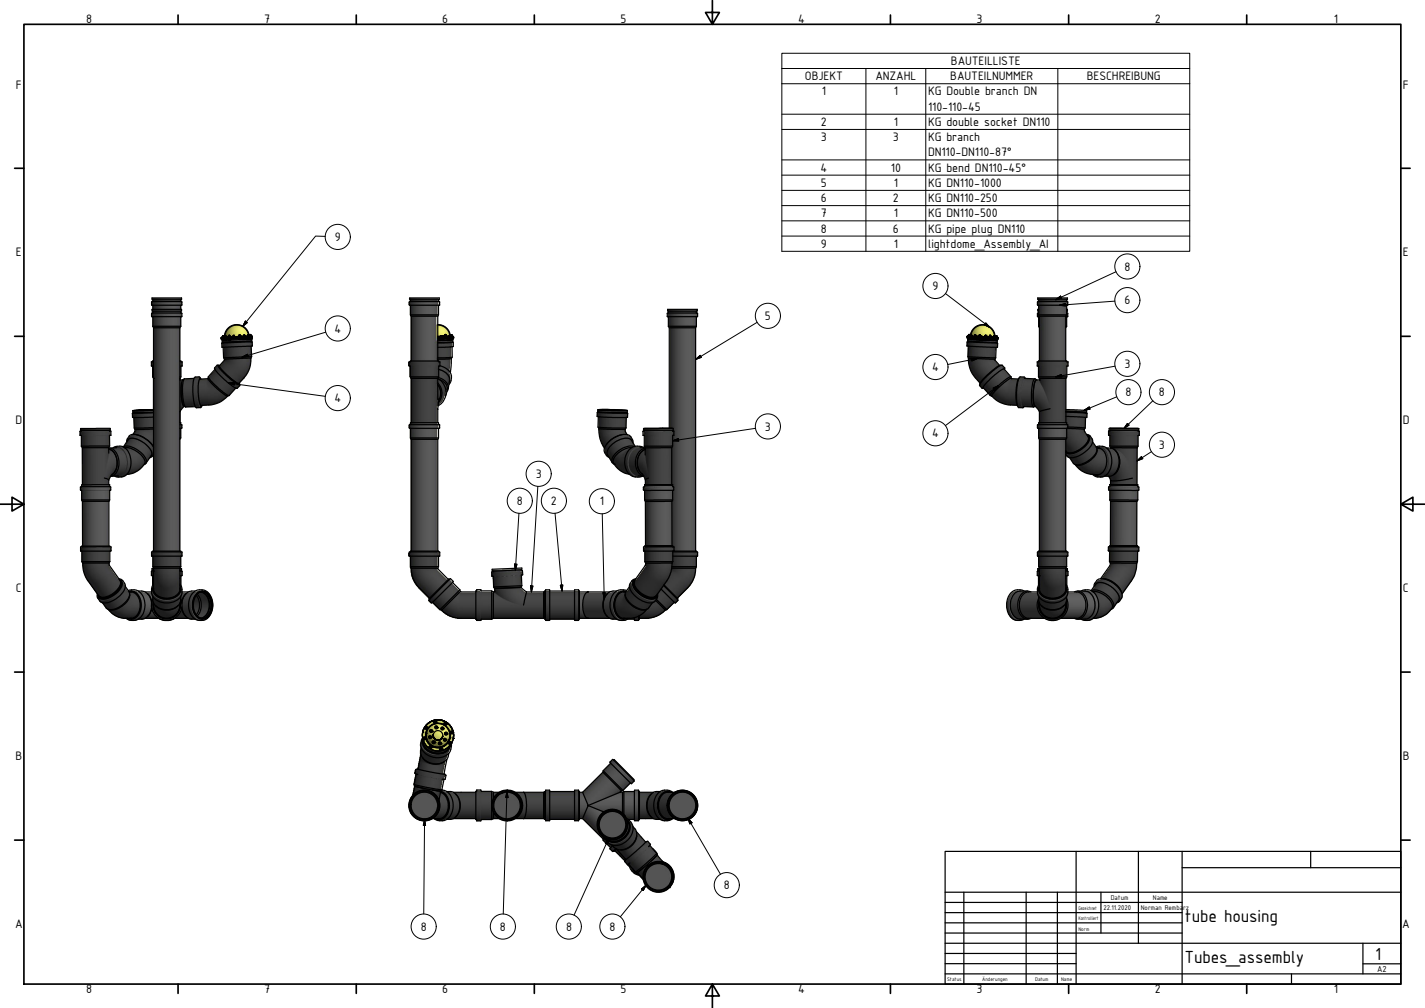
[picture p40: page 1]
EIL; LIS; EIB; pip; lig; sin; eic; lie

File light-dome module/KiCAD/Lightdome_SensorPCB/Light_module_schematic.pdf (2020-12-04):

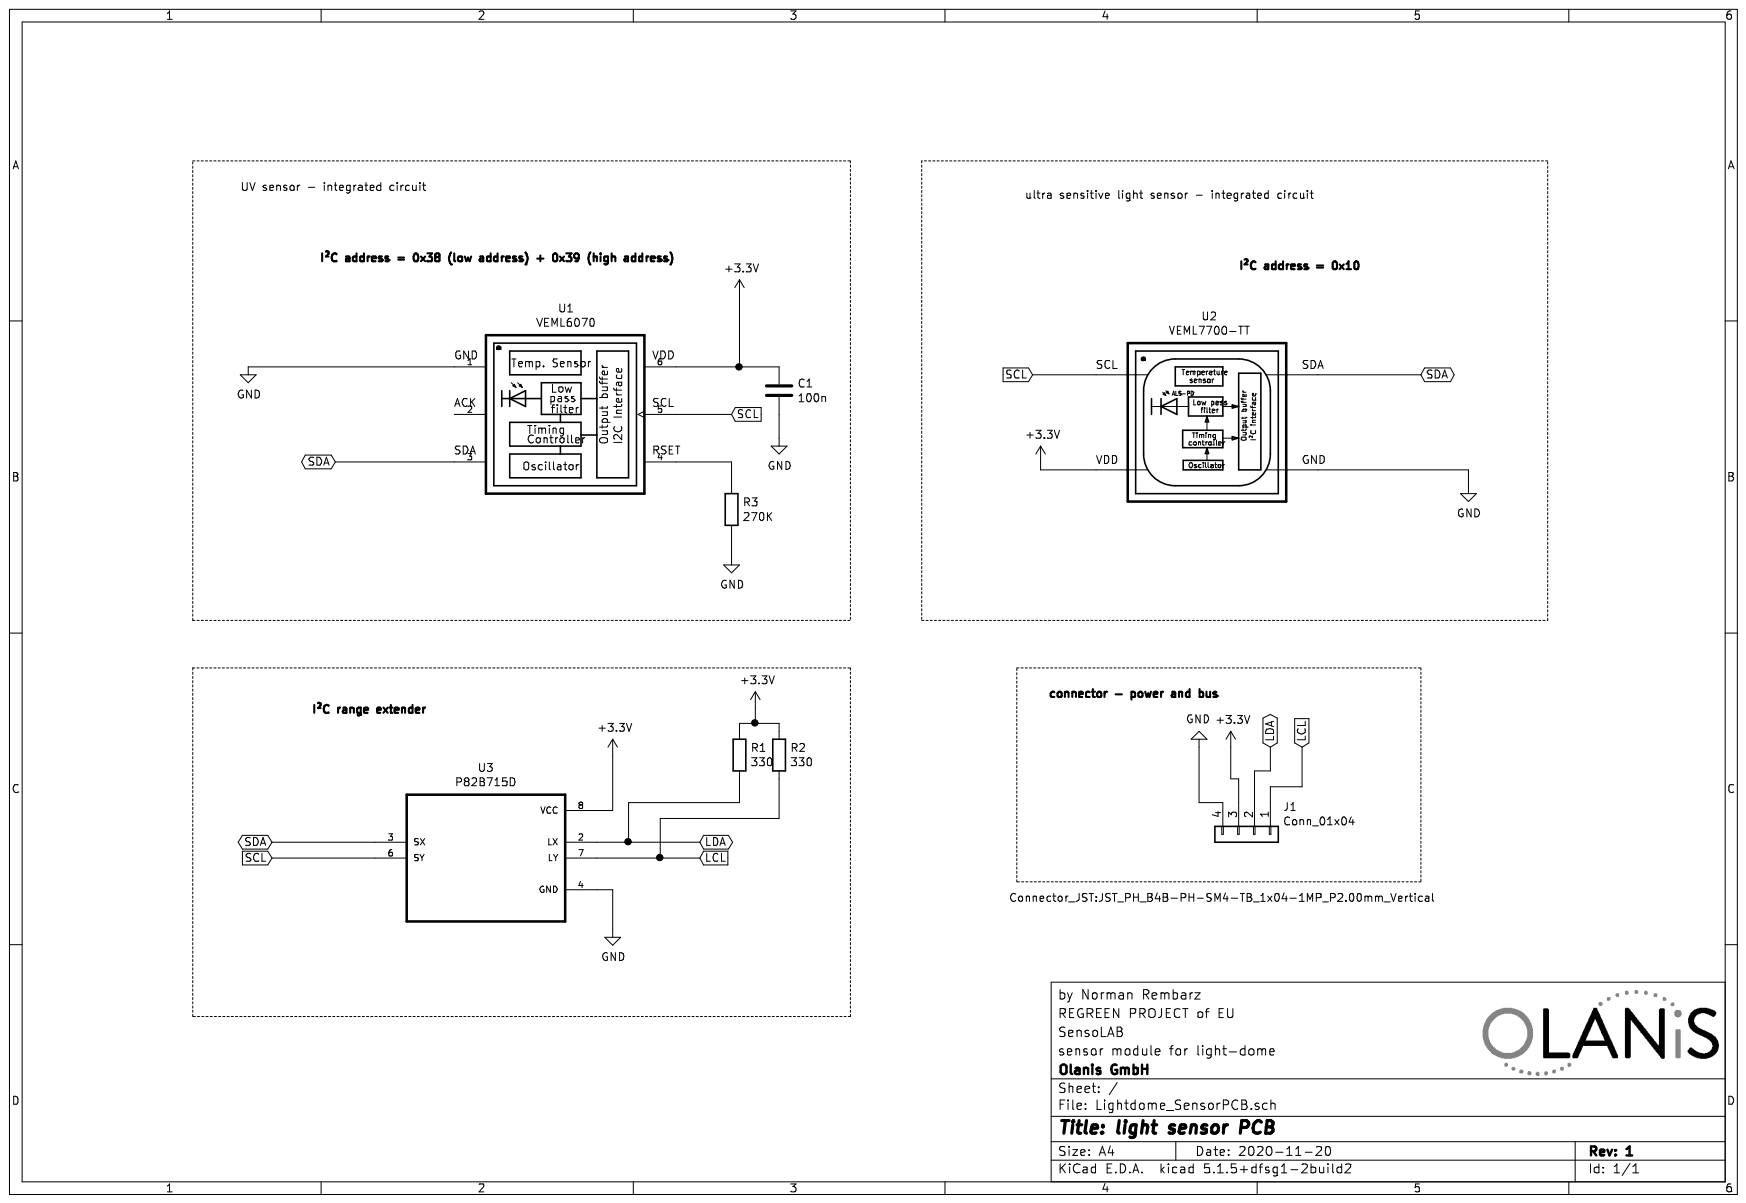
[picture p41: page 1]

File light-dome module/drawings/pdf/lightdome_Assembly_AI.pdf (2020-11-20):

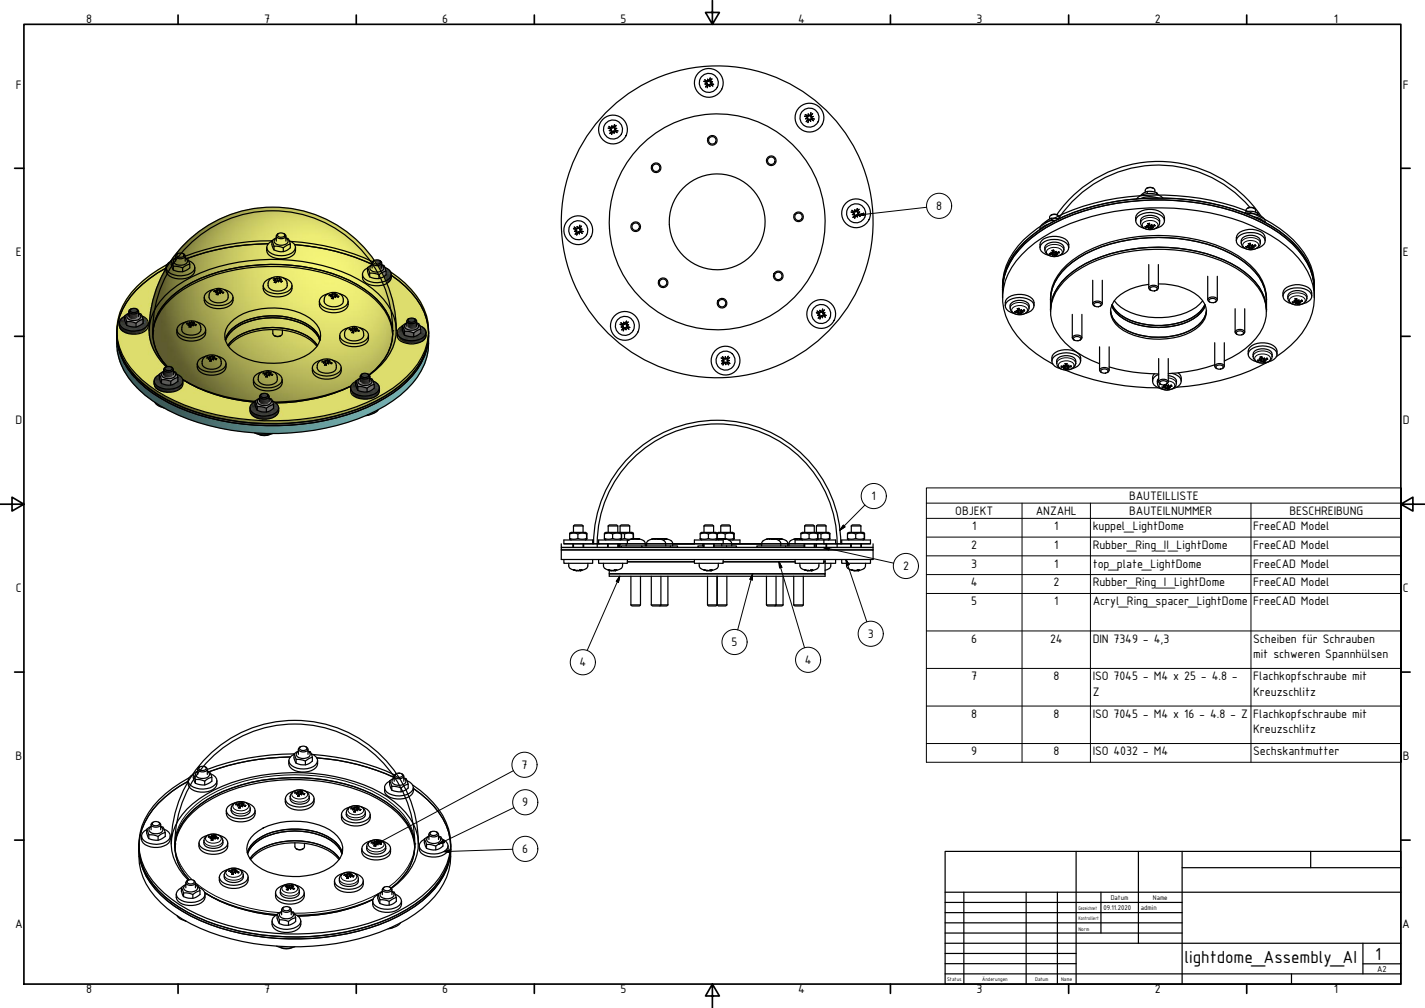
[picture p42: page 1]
BAUTEILLISTE; OBJEKT; ANZAHL; BAUTEILNUMMER; BESCHREIBUNG; kuppel_LightDome; FreeCAD Model; Rubber_Ring_II_LightDome; top_plate_LightDome; Rubber_Ring_I_LightDome; Acryl_Ring_spacer_LightDome; DIN 7349 - 4,3; Flachkopfschraube mit Kreuzschlitz; ISO 7045 - M4 x 25 - 4.8 - Z; ISO 7045 - M4 x 16 - 4.8 - Z; ISO 4032 - M4; Sechskantmutter; lightdome_Assembly_AI; Status; |nderungen; Datum; Name; Gezeichnet; Kontrolliert; Norm; admin

Scheiben f¯r Schrauben
mit schweren Spannh¯lsen

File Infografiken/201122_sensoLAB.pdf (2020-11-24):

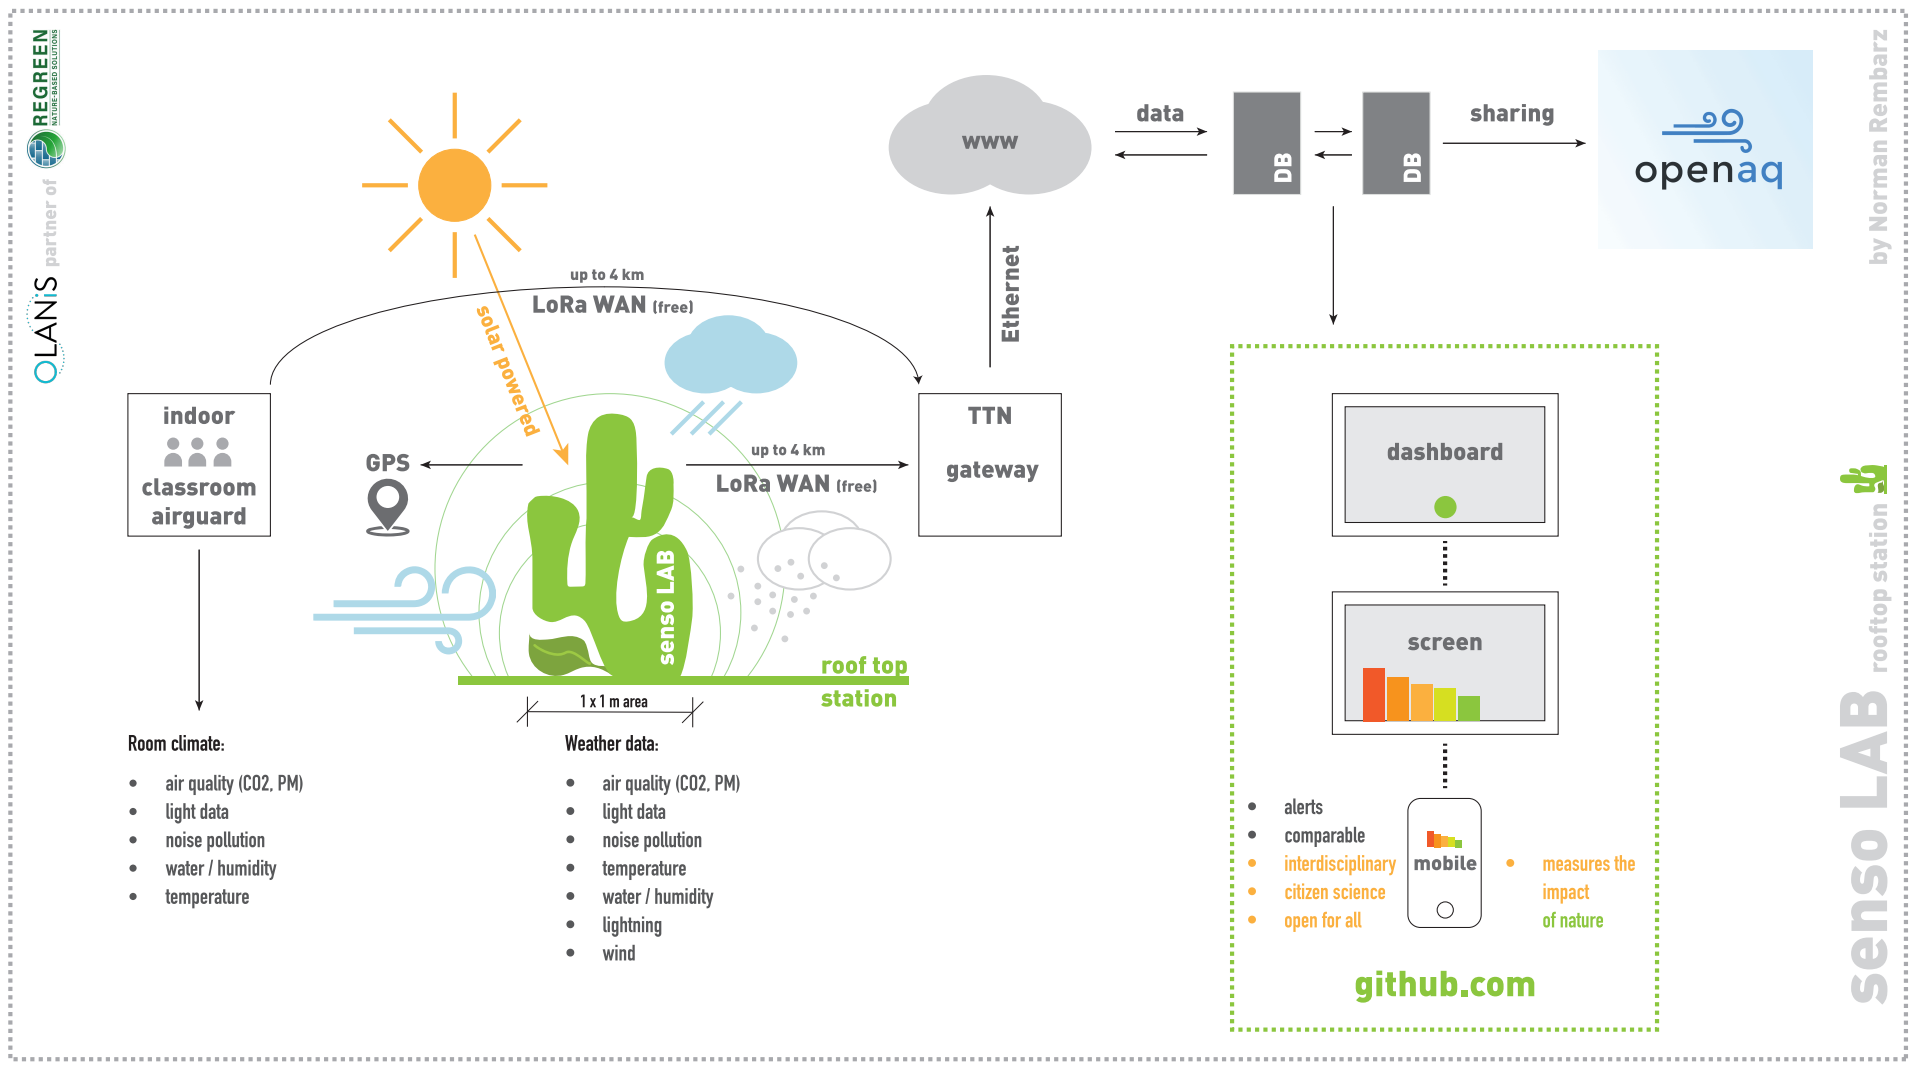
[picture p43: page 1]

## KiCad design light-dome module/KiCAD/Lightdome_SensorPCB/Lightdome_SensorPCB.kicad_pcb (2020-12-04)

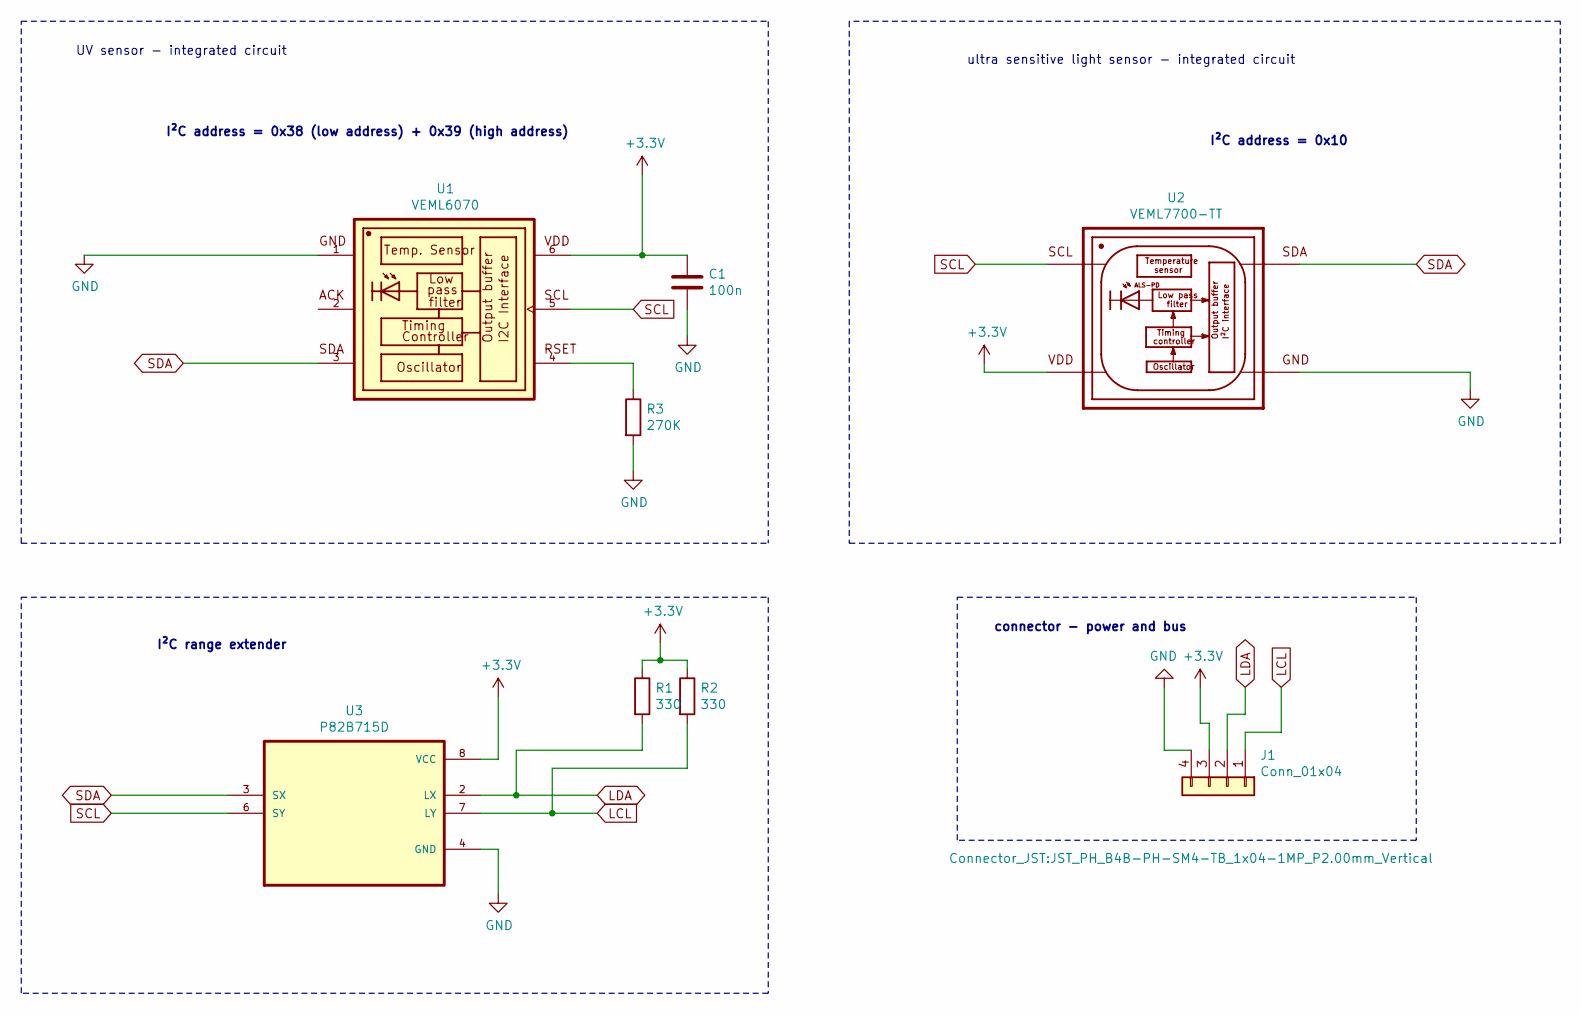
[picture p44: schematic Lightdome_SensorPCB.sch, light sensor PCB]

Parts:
C1: 100n; C_0603_1608Metric_Pad1.05x0.95mm_HandSolder
J1: Conn_01x04; JST_PH_B4B-PH-SM4-TB_1x04-1MP_P2.00mm_Vertical
R1, R2: 330; R_1206_3216Metric_Pad1.42x1.75mm_HandSolder
R3: 270K; R_0603_1608Metric_Pad1.05x0.95mm_HandSolder
U1: VEML6070; PHODET_VEML6070
U2: VEML7700-TT; XDCR_VEML7700-TT; PARTREV 1.3
U3: P82B715D; SOIC127P599X175-8N

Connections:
+3V3: C1.1, J1.3, R1.1, R2.1, U1.6, U2.2, U3.8 (VCC)
GND: C1.2, J1.4, R3.2, U1.1, U2.3, U3.4 (GND)
LCL: J1.1, R2.2, U3.7 (LY)
LDA: J1.2, R1.2, U3.2 (LX)
unnamed: R3.1, U1.4
SCL: U1.5, U2.1, U3.6 (SY)
SDA: U1.3, U2.4, U3.3 (SX)

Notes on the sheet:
UV sensor - integrated circuit
ultra sensitive light sensor - integrated circuit
I²C address = 0x10
I²C address = 0x38 (low address) + 0x39 (high address)
I²C range extender
connector - power and bus

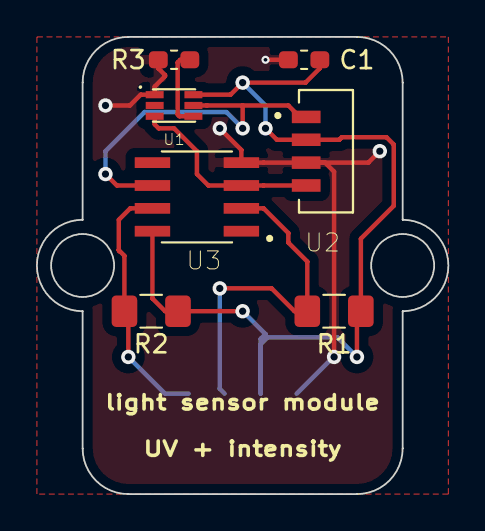
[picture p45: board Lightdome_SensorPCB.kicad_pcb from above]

Board: 2 copper layers, 22.9 x 25.4 mm, 8 parts (1 on the bottom side), 7 nets.

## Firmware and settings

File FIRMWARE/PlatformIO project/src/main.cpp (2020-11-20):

#include <Arduino.h>
/*******************************************************************************
 * Copyright (c) 2015 Thomas Telkamp and Matthijs Kooijman
 *
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
 * This uses OTAA (Over-the-air activation), where a DevEUI and
 * application key is configured, which are used in an over-the-air
 * activation procedure where a DevAddr and session keys are
 * assigned/generated for use with all further communication.
 *
 * Note: LoRaWAN per sub-band duty-cycle limitation is enforced (1% in
 * g1, 0.1% in g2), but not the TTN fair usage policy (which is probably
 * violated by this sketch when left running for longer)!
 * To use this sketch, first register your application and device with
 * the things network, to set or generate an AppEUI, DevEUI and AppKey.
 * Multiple devices can use the same AppEUI, but each device has its own
 * DevEUI and AppKey.
 *
 * Do not forget to define the radio type correctly in config.h.
 *
 *******************************************************************************/
#include <lmic.h>
#include <hal/hal.h>
#include <SPI.h>
#include <TinyGPS++.h>
#include <HardwareSerial.h>
#include <list>

#include "sps30.h"
#include "SparkFun_SCD30_Arduino_Library.h" //Click here to get the library: http://librarymanager/All#SparkFun_SCD30
#include "Adafruit_VEML7700.h"
#include "Adafruit_VEML6070.h"
#include <Adafruit_ADS1015.h>
#include <Adafruit_BME280.h>
#include "config.h"


//Power Management mit AXP1992 Chip
#include <esp_sleep.h>
#include <axp20x.h>
AXP20X_Class pmu;

SPS30 sps30;

// This EUI must be in little-endian format, so least-significant-byte
// first. When copying an EUI from ttnctl output, this means to reverse
// the bytes. For TTN issued EUIs the last bytes should be 0xD5, 0xB3,
// 0x70.
void os_getArtEui (u1_t* buf) { memcpy_P(buf, APPEUI, 8);}
// This should also be in little endian format, see above.
void os_getDevEui (u1_t* buf) { memcpy_P(buf, DEVEUI, 8);}
// This key should be in big endian format (or, since it is not really a
// number but a block of memory, endianness does not really apply). In
// practice, a key taken from ttnctl can be copied as-is.
// The key shown here is the semtech default key.
void os_getDevKey (u1_t* buf) {  memcpy_P(buf, APPKEY, 16);}

TinyGPSPlus gps;

HardwareSerial GPSSerial(1);

struct __attribute__((__packed__)) DataPayload {
  uint16_t pressure;
  uint16_t wind_direction;
  uint16_t light_intensity;
  uint16_t CO2value;
  int8_t temperature;
  uint8_t humidity;
  uint8_t uv_index;
  uint8_t wind_speed;
  uint8_t light_parameters;
  uint8_t wind_peak;
};

struct DataPayloadGPS {
  int32_t gps_lng;
  int32_t gps_lat;
  int16_t gps_alt;
};

struct __attribute__((__packed__)) DataPayloadSPS30 {
  uint16_t mass_pm1;
  uint16_t mass_pm2;
  uint16_t mass_pm10;
};

static DataPayload data;
static DataPayloadGPS dataGPS;
static DataPayloadSPS30 dataSPS30;
static osjob_t preparesendjob;
static osjob_t sendjob;
static osjob_t sendjobaftergps;
static osjob_t luminationjob;
static osjob_t uvjob;
static osjob_t bmejob;
static osjob_t adsjob;
static osjob_t airsensorco2job;
static osjob_t sps30job;
static std::list<uint8_t> wind_mean;
static uint8_t wind_peak;
static SemaphoreHandle_t wind_speed_mtx = xSemaphoreCreateMutex();

// Pin mapping
const lmic_pinmap lmic_pins = {
  .nss = 18,
  .rxtx = LMIC_UNUSED_PIN,
  .rst = 23,  // war 5 bei v_0_7 - soll 23 sein bei > v_1_1
  .dio = {26, 33, 32},
};

// BME 280 foo
Adafruit_BME280 bme;

// UV Sensor
Adafruit_VEML6070 uv = Adafruit_VEML6070();

// Light sensor
Adafruit_VEML7700 light = Adafruit_VEML7700();

// ADS1115 ADC
Adafruit_ADS1115 ads;

//SCD30 Co2 Sensor
SCD30 airsensorCO2;

// Only send the GPS coordinates once after having a lock.
bool gpsWasSent = false;

uint8_t read_light_gain_from_data() {
  return (uint8_t)(data.light_parameters & 0x03);
}

uint8_t read_light_it_from_data() {
  return (uint8_t)((data.light_parameters >> 2) & 0x0F);
}

void set_lumination_reader_parameters() {
  light.setGain(read_light_gain_from_data());
  light.setIntegrationTime(read_light_it_from_data());
}

void write_light_gain_to_data(uint8_t gain) {
  data.light_parameters = (0xFC & data.light_parameters) + gain;
  set_lumination_reader_parameters();
}

void write_light_it_to_data(uint8_t it) {
  data.light_parameters = (0x03 & data.light_parameters) + (it<<2);
  set_lumination_reader_parameters();
}

void read_lumination_job(osjob_t* j) {
  // printf("Light: 0x%x\n", data.light_parameters);
  while (true) {
    data.light_intensity = (int16_t)(light.readALS());
    uint8_t gain = read_light_gain_from_data();
    uint8_t it = read_light_it_from_data();
    // printf("Gain: 0x%x, it: 0x%x\n", gain, it);
    if (gain == VEML7700_GAIN_1_8 && data.light_intensity < LIGHT_THRESHHOLD_DOWN_HIGH) {
      write_light_gain_to_data(VEML7700_GAIN_2);
    } else if (gain == VEML7700_GAIN_2 && it == VEML7700_IT_25MS && data.light_intensity < LIGHT_THRESHHOLD_DOWN_LOW) {
      write_light_it_to_data(VEML7700_IT_800MS);
    } else if (gain == VEML7700_GAIN_2 && it == VEML7700_IT_800MS && data.light_intensity > LIGHT_THREADHHOLD_UP_LOW) {
      write_light_it_to_data(VEML7700_IT_25MS);
    } else if (gain == VEML7700_GAIN_2 && it == VEML7700_IT_25MS && data.light_intensity > LIGHT_THRESHHOLD_UP_HIGH) {
      write_light_gain_to_data(VEML7700_GAIN_1_8);
    } else {
      break;
    }
    os_setTimedCallback(&luminationjob, os_getTime()+sec2osticks(1), read_lumination_job);
    return;
  }
  // printf("New Gain: 0x%x, it: 0x%x, Light: %d\n", read_light_gain_from_data(), read_light_it_from_data(), data.light_intensity);
  light.powerSaveEnable(true);
}

void read_lumination() {
  light.powerSaveEnable(false);
  os_setTimedCallback(&luminationjob, os_getTime()+sec2osticks(1), read_lumination_job);
}

void read_uv_job(osjob_t* j) {
  uint16_t uv_value = uv.readUV();
  float it_factor[4] = {0.5, 1, 2, 4};
  data.uv_index = (uint8_t)round(uv_value / 280 * (UV_R_SET_KOHM / 270) / it_factor[UV_IT]);
  uv.sleep(true);
}

void read_uv() {
  uv.sleep(false);
  os_setTimedCallback(&uvjob, os_getTime()+sec2osticks(4), read_uv_job);
}

void read_bme_job(osjob_t* j) {
  data.temperature = (int8_t)((bme.readTemperature() + 50) * 2);
  data.pressure = (uint16_t)(bme.readPressure() / 10);
  data.humidity = (uint8_t)(bme.readHumidity());
}

void read_bme() {
  bme.takeForcedMeasurement();
  os_setTimedCallback(&bmejob, os_getTime() + sec2osticks(1), read_bme_job);
}

void read_ads_job(osjob_t* j) {
  xSemaphoreTake(wind_speed_mtx, portMAX_DELAY);
  data.wind_direction = (uint16_t) (ads.readADC_SingleEnded(0)*360)/24500;
  uint8_t wind_speed = (uint8_t)(((ads.readADC_SingleEnded(1)*3.3/1023.0*6.0)-0.2516)*6.0); 
  wind_mean.push_back(wind_speed);
  wind_peak = max(wind_peak, wind_speed);
  xSemaphoreGive(wind_speed_mtx);
  os_setTimedCallback(&adsjob, os_getTime() + sec2osticks(10), read_ads_job);
}

void read_ads() {
  xSemaphoreTake(wind_speed_mtx, portMAX_DELAY);
  uint64_t wind_speed = 0;
  wind_mean.sort();
  if (wind_mean.size() > 0) {
    int five_percent = (int)floor(wind_mean.size() / 100 * 5);
    int i = 0;
    for (std::list<uint8_t>::iterator wm = wind_mean.begin(); wm != wind_mean.end(); wm++) {
      if (i >= five_percent && i <= wind_mean.size() - five_percent) {
        wind_speed += *wm;
      }
    }
    data.wind_speed = wind_speed / (wind_mean.size() - (five_percent * 2));
    data.wind_peak = wind_peak;

    wind_mean.clear();
    wind_peak = 0;
  }
  xSemaphoreGive(wind_speed_mtx);
}

void read_airsensorco2_job(osjob_t* j) {
  data.CO2value = airsensorCO2.getCO2();
  airsensorCO2.setForcedRecalibrationFactor(airsensorCO2.getCO2());   //wenn der aktuelle Messwert <400 o. >2000 , dann wird Kalibrierung angestoßen
}

void read_airsensorco2() {
  os_setTimedCallback(&airsensorco2job, os_getTime() + sec2osticks(3), read_airsensorco2_job);
}

void read_sps30_job(osjob_t* j) {
  struct sps_values v;
  sps30.GetValues(&v);
  dataSPS30.mass_pm1 = v.MassPM1 > 10 ? 65535 : (uint16_t)(v.MassPM1 * 6000);
  dataSPS30.mass_pm2 = v.MassPM2 > 10 ? 65535 : (uint16_t)(v.MassPM2 * 6000);
  dataSPS30.mass_pm10 = v.MassPM10 > 10 ? 65535 : (uint16_t)(v.MassPM10 * 6000);
  sps30.stop();
  // sps30.sleep();
}

void read_sps30() {
  // sps30.wakeup();
  if (!sps30.probe()) {
    Serial.println("Could not probe SPS30");
  }
  sps30.start();
  os_setTimedCallback(&sps30job, os_getTime() + sec2osticks(30), read_sps30_job);
}

int dataToSend = 1;

void do_send(osjob_t* j){
  // GPS sending
  Serial.print("GPS valid: ");
  Serial.println(gps.satellites.value());
  
  if (gps.location.isValid() && gps.altitude.isValid() && gps.satellites.isValid() && gps.satellites.value() > 5 && !gpsWasSent) {   
    dataGPS.gps_lng = (int32_t)(gps.location.lng() / 180 * INT32_MAX);
    dataGPS.gps_lat = (int32_t)(gps.location.lat() / 90 * INT32_MAX);
    dataGPS.gps_alt = (int16_t)(gps.altitude.meters());
    if (LMIC.opmode & OP_TXRXPEND) {
        Serial.println(F("GPS OP_TXRXPEND, not sending"));
    } else {
        // Prepare upstream data transmission at the next possible time.
        int result = LMIC_setTxData2(1, (byte*)&dataGPS, sizeof(dataGPS), 0);
        if (result) {
          Serial.printf("Packet queuing failed: %d\n", result);
        }
        Serial.println(F("GPS Packet queued"));
        gpsWasSent = true;
    }
    if (!pmu.begin(Wire, AXP192_SLAVE_ADDRESS)) {
      pmu.setPowerOutPut(AXP192_LDO3, AXP202_OFF);
    }
    os_setTimedCallback(&sendjobaftergps, os_getTime()+sec2osticks(60), do_send);
    return;
  }

  byte* send_data;
  uint8_t send_data_len;
  uint8_t send_port;

  switch (dataToSend) {
    case 0:
      send_port = 2;
      Serial.println("Sending wheather data.");
      send_data = (byte*)&data;
      send_data_len = sizeof(data);
      break;
    case 1:
      send_port = 3;
      Serial.println("Sending air ppm data.");
      send_data = (byte*)&dataSPS30;
      send_data_len = sizeof(dataSPS30);
      break;
    default:
      Serial.println("Not sending any data - invalid dataToSend");
      dataToSend = 0;
      return;
  }
  dataToSend++;
  if (dataToSend > 1) {
    dataToSend = 0;
  }
  
  Serial.printf("Data size: %d\n", send_data_len);
  for(int i=0;i<send_data_len;i++)
  {
    Serial.println(send_data[i]);
  }

  // Check if there is not a current TX/RX job running
  if (LMIC.opmode & OP_TXRXPEND) {
      Serial.println(F("OP_TXRXPEND, not sending"));
  } else {
      // Prepare upstream data transmission at the next possible time.
      int result = LMIC_setTxData2(send_port, send_data, send_data_len, 0);
      if (result) {
        Serial.printf("Packet queuing failed: %d\n", result);
      }
      Serial.println(F("Packet queued"));
  }
  // Next TX is scheduled after TX_COMPLETE event.
}

void prepare_send(osjob_t* j) {
  switch (dataToSend) {
    case 0:
      read_lumination();
      read_uv();
      read_bme();
      read_ads();
      read_airsensorco2();
      break;
    case 1:
      read_sps30();
      Serial.println("Lesen SPS30");
      break;
  }
  os_setTimedCallback(&sendjob, os_getTime()+sec2osticks(35), do_send);
  os_setTimedCallback(&preparesendjob, os_getTime()+sec2osticks(TX_INTERVAL), prepare_send);
}

void onEvent (ev_t ev) {
  Serial.print(os_getTime());
  Serial.print(": ");
  switch(ev) {
    case EV_SCAN_TIMEOUT:
      Serial.println(F("EV_SCAN_TIMEOUT"));
      break;
    case EV_BEACON_FOUND:
      Serial.println(F("EV_BEACON_FOUND"));
      break;
    case EV_BEACON_MISSED:
      Serial.println(F("EV_BEACON_MISSED"));
      break;
    case EV_BEACON_TRACKED:
      Serial.println(F("EV_BEACON_TRACKED"));
      break;
    case EV_JOINING:
      Serial.println(F("EV_JOINING"));
      break;
    case EV_JOINED:
      Serial.println(F("EV_JOINED"));
      // Disable link check validation (automatically enabled
      // during join, but not supported by TTN at this time).
      LMIC_setLinkCheckMode(0);
      break;
    case EV_RFU1:
      Serial.println(F("EV_RFU1"));
      break;
    case EV_JOIN_FAILED:
      Serial.println(F("EV_JOIN_FAILED"));
      break;
    case EV_REJOIN_FAILED:
      Serial.println(F("EV_REJOIN_FAILED"));
      break;
    case EV_TXCOMPLETE:
      Serial.println(F("EV_TXCOMPLETE (includes waiting for RX windows)"));
      if (LMIC.txrxFlags & TXRX_ACK)
        Serial.println(F("Received ack"));
      if (LMIC.dataLen) {
        Serial.println(F("Received "));
        Serial.println(LMIC.dataLen);
        Serial.println(F(" bytes of payload"));
      }
      break;
    case EV_LOST_TSYNC:
      Serial.println(F("EV_LOST_TSYNC"));
      break;
    case EV_RESET:
      Serial.println(F("EV_RESET"));
      break;
    case EV_RXCOMPLETE:
      // data received in ping slot
      Serial.println(F("EV_RXCOMPLETE"));
      break;
    case EV_LINK_DEAD:
      Serial.println(F("EV_LINK_DEAD"));
      break;
    case EV_LINK_ALIVE:
      Serial.println(F("EV_LINK_ALIVE"));
      break;
    default:
      Serial.printf("Unknown event 0x%x (%d)\n", ev, ev);
      break;
  }
}

void AXP192_power(bool on) {
  if (on) {
    pmu.setPowerOutPut(AXP192_LDO2, AXP202_ON);  // Lora on T-Beam V1.0
    pmu.setPowerOutPut(AXP192_LDO3, AXP202_ON);  // Gps on T-Beam V1.0
    pmu.setPowerOutPut(AXP192_DCDC1, AXP202_ON); // OLED on T-Beam v1.0
    pmu.setChgLEDMode(AXP20X_LED_OFF);
    // pmu.setPowerOutPut(AXP192_EXTEN, AXP202_ON);
    //pmu.setChgLEDMode(AXP20X_LED_BLINK_1HZ);
  } else {
    pmu.setChgLEDMode(AXP20X_LED_OFF);
    pmu.setPowerOutPut(AXP192_DCDC1, AXP202_OFF);
    pmu.setPowerOutPut(AXP192_LDO3, AXP202_OFF);
    pmu.setPowerOutPut(AXP192_LDO2, AXP202_OFF);
    // pmu.setPowerOutPut(AXP192_EXTEN, AXP202_OFF);
  }
}

void AXP192_init() {      
  if (pmu.begin(Wire, AXP192_SLAVE_ADDRESS)) {
    Serial.println("AXP192 PMU initialization failed");
  } else {
    Serial.println("Initialzation...");
    // configure AXP192
    pmu.setDCDC1Voltage(3500);              // for external OLED display
    pmu.setTimeOutShutdown(false);          // no automatic shutdown
    pmu.setTSmode(AXP_TS_PIN_MODE_DISABLE); // TS pin mode off to save power

    // switch ADCs on
    pmu.adc1Enable(AXP202_BATT_VOL_ADC1, true);
    pmu.adc1Enable(AXP202_BATT_CUR_ADC1, true);
    pmu.adc1Enable(AXP202_VBUS_VOL_ADC1, true);
    pmu.adc1Enable(AXP202_VBUS_CUR_ADC1, true);

    pmu.setLDO2Voltage(3300);
    pmu.setLDO3Voltage(3300);

    // switch power rails on
    AXP192_power(true);

    Serial.println("AXP192 PMU initialized");
  }
}

void setup() {
  Serial.begin(9600);
  Serial.println(F("Starting"));
  //BME280 foo
  Wire.begin(21,22);
  int timeout = 0;

  GPSSerial.begin(GPSBaud, SERIAL_8N1, GPS_TX, GPS_RX);
  GPSSerial.setTimeout(2);

  AXP192_init();
  Serial.println("AXP192 initialisiert");
  delay(2000);
  AXP192_power(true);
  Serial.println("AXP192 powered on peripherals");
  delay(2000);
 

  while(!bme.begin(0x76,&Wire))
  {
    Serial.println("Could not find BME280 sensor!");
    delay(500);
    if (timeout++ == 10) {
      Serial.println("Continuing...");
      break;
    }
  }
  bme.setSampling(Adafruit_BME280::MODE_FORCED, Adafruit_BME280::SAMPLING_X16,
    Adafruit_BME280::SAMPLING_X16, Adafruit_BME280::SAMPLING_X16, Adafruit_BME280::FILTER_OFF,
    Adafruit_BME280::STANDBY_MS_500);
  //ENDE BME280 foo

  //UV Sensor initialisieren
  uv.begin(UV_IT);

  // ADS1115 init
  
  // The ADC input range (or gain) can be changed via the following
  // functions, but be careful never to exceed VDD +0.3V max, or to
  // exceed the upper and lower limits if you adjust the input range!
  // Setting these values incorrectly may destroy your ADC!
  //                                                                ADS1015  ADS1115
  //                                                                -------  -------
  // ads.setGain(GAIN_TWOTHIRDS);  // 2/3x gain +/- 6.144V  1 bit = 3mV      0.1875mV (default)
  ads.setGain(GAIN_ONE);        // 1x gain   +/- 4.096V  1 bit = 2mV      0.125mV
  // ads.setGain(GAIN_TWO);        // 2x gain   +/- 2.048V  1 bit = 1mV      0.0625mV
  // ads.setGain(GAIN_FOUR);       // 4x gain   +/- 1.024V  1 bit = 0.5mV    0.03125mV
  // ads.setGain(GAIN_EIGHT);      // 8x gain   +/- 0.512V  1 bit = 0.25mV   0.015625mV
  // ads.setGain(GAIN_SIXTEEN);    // 16x gain  +/- 0.256V  1 bit = 0.125mV  0.0078125mV
  
  ads.begin();


  // VEML7700 light sensor initialisation
  light.begin();
  write_light_gain_to_data(VEML7700_GAIN_1_8);
  write_light_it_to_data(VEML7700_IT_25MS);
  Serial.print("Gain VEML7700: ");
  Serial.println(light.getGain());
  Serial.print("Integration time VEML7700: ");
  Serial.println(light.getIntegrationTime());
  //light.powerSaveEnable(true);
  //light.setPowerSaveMode(VEML7700_POWERSAVE_MODE4);
  light.setLowThreshold(0);
  light.setHighThreshold(260);
  light.interruptEnable(true);
  delay(900);
  Serial.println("VEML7700 Interrupt: ");
  Serial.println(light.interruptStatus());

  // Feinstaubsensor
  sps30.begin(&Wire);

  // CO2 Sensor init
  airsensorCO2.begin();
  airsensorCO2.setMeasurementInterval(20); //Change number of seconds between measurements: 2 to 1800 (30 minutes)
  airsensorCO2.setAutoSelfCalibration(true);
  delay(2000);
  //My desk is ~1600m above sealevel
  airsensorCO2.setAltitudeCompensation(113); //Set altitude of the sensor in m

  //Pressure in Boulder, CO is 24.65inHg or 834.74mBar
  Serial.print("aktueller Luftdruck fuer Kalibrierung SCD30 ");
  Serial.println((int)(bme.readPressure()/100));
  airsensorCO2.setAmbientPressure((int)bme.readPressure()/100); //Current ambient pressure in mBar: 700 to 1200
  airsensorCO2.setTemperatureOffset(1); //Optionally we can set temperature offset to 5°C
  

  // Serial.println("wait for GPS");
  // waiting time for GPS module
  // delay(16000);

  // LMIC init
  os_init();
  // Reset the MAC state. Session and pending data transfers will be discarded.
  LMIC_reset();
  // Start job (sending automatically starts OTAA too)
  prepare_send(&preparesendjob);
  read_ads_job(&adsjob);
}

int previousMillis = millis();

void loop() {
  if (previousMillis + 1000 < millis()) {
    previousMillis = millis();
    while (GPSSerial.available()) {
      uint8_t data = GPSSerial.read();
      gps.encode(data);
      //printf("%c", data);
    }
  }

  os_runloop_once();
}

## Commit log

2020-10-08 added documentation wind sensor
2020-11-20 not needed for public
    [solar_panel_mount_bracket_1.step, solar_panel_mount_bracket_2.step]
2020-11-24 added KiCADF project for light sensor PCB
    [Lightdome_SensorPCB-B_Mask.gbr, Lightdome_SensorPCB-B_Paste.gbr, Lightdome_SensorPCB-B_SilkS.gbr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]
2020-11-25 added tube drawings
2020-11-27 added BOM
2020-11-27 some changes in bill of material
2020-12-04 changes in light module PCB
    [Lightdome_SensorPCB-B_Mask.gbr, Lightdome_SensorPCB-B_Paste.gbr, Lightdome_SensorPCB-B_SilkS.gbr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]
2020-12-04 added schematic
2020-12-04 changes in BOM
